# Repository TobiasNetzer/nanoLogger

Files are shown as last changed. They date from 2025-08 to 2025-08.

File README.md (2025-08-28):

# Block Diagram

Here is a simplified block diagram of the data logger. To measure the current of a device, the data logger is simply connected in series between the voltage source and the DUT/load.

The current flow creates a small voltage drop across the selected shunt resistor, which is amplified by a factor of 100. The output voltage is then measured by the microcontroller's internal ADC.
A change of the current range is also observed by the microcontroller, to correctly convert the measured current.

An external trigger signal can optionally be connected. This allows to start the measurement on a rising or falling edge. Perfect to always have the same starting point of a measurement, for example when the DUT enters active mode.

Status LEDs provide the user with information about the device's current state/mode, for example: logger in standby mode, or data recording in progress.

The captured data is buffered internally in the microcontroller and then transferred to a PC via an isolated USB 2.0 interface.

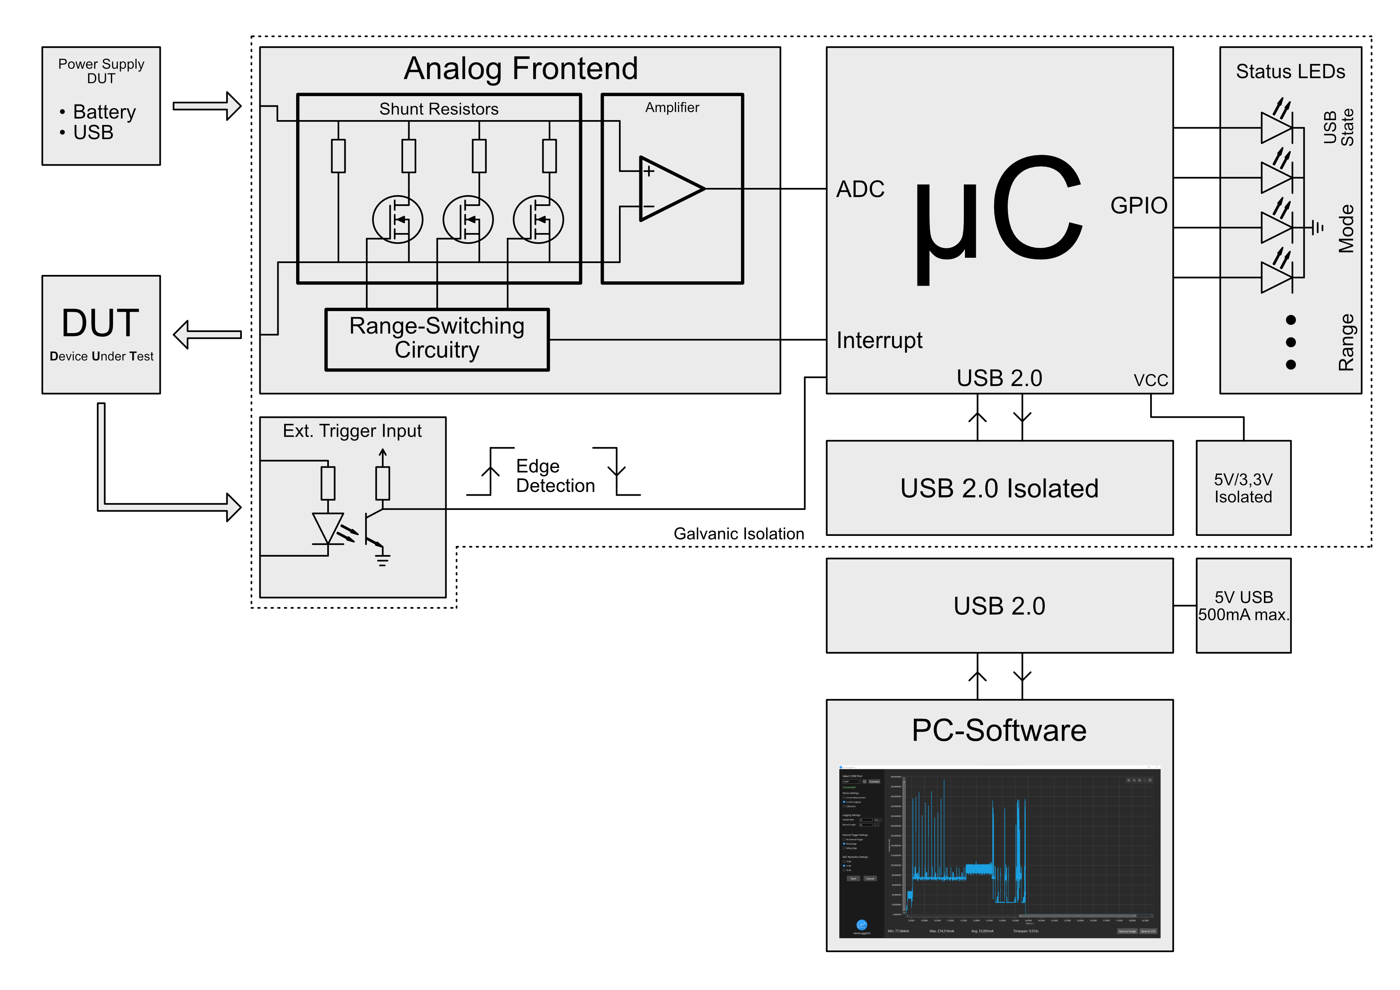
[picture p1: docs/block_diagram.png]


# Hardware

I've written a very detailed explanation as part of the project documentation. You can read more about it [here](docs/Technikerarbeit_Tobias_Netzer.pdf) if you are interested in the design aspects and my thoughts behind them. This is also where you can find all the schematics and technical drawings. The documentation was however written in German.

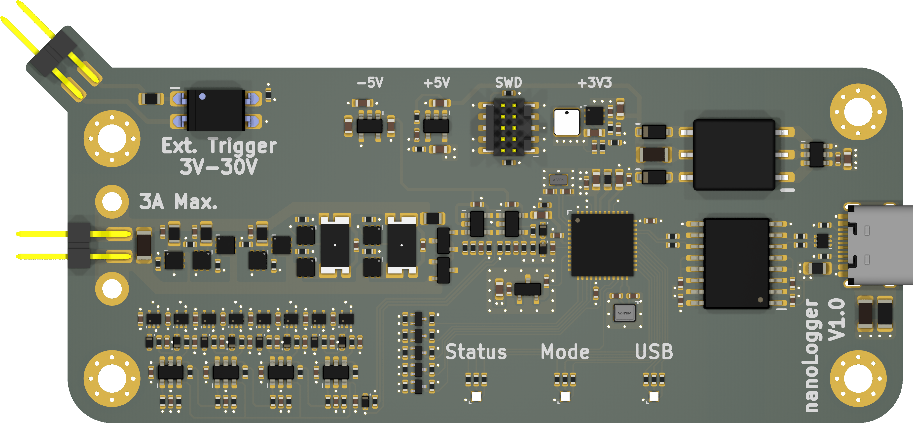
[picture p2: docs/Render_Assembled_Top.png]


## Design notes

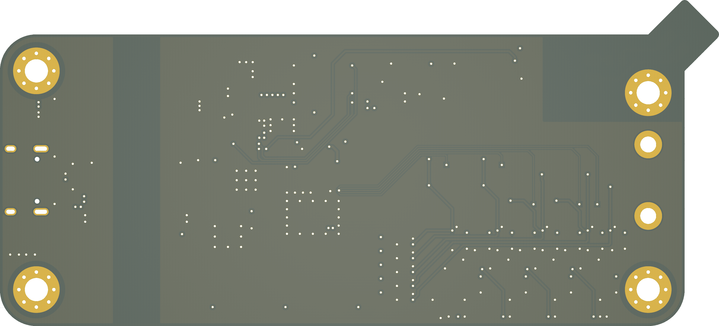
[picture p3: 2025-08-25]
docs/Render Bot.png

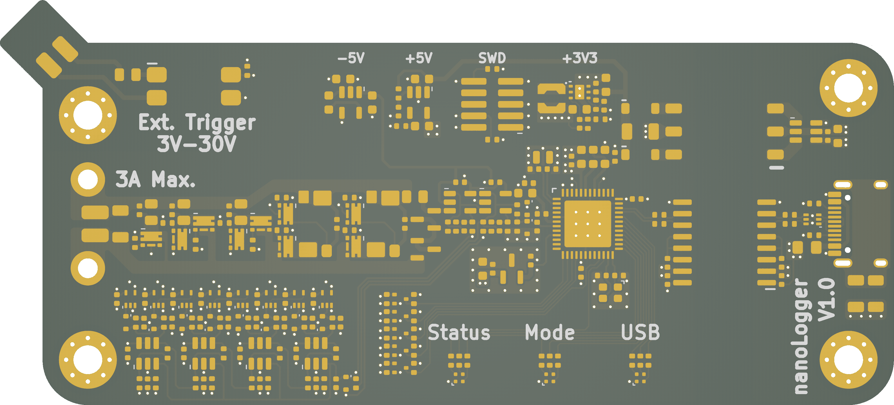
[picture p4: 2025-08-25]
docs/Render Top.png

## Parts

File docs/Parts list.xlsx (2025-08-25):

Position | Menge | Bauteilbezeichnung | Wert/Typ | Beschreibung | Hersteller | Hersteller-Nr. | Lieferant | Lieferant-Nr. | Stückpreis | Gesamtpreis
1 | 2 | C1, C35 | 10nF | 10nF-1%-1206-C0G-630V | Kemet | C1206C103FBGACAUTO | Mouser | 80-C1206C103FBGAUTO | 1.03 € | 2.06 €
2 | 6 | C2, C8, C12, C19, C23, C27 | 10µF | 10µF-20%-0603-X5R-10V | Kemet | C0603C106M8PACTU | Mouser | 80-C0603C106M8PACTU | 0.43 € | 2.58 €
3 | 33 | C3, C4, C5, C6, C7, C9, C10, C14, C20, C21, C22, C24, C26, C28, C36, C37, C38, C39, C40, C41, C42, C46, C47, C48, C49, C62, C63, C64, C65, C66, C67, C68, C69 | 100nF | 100nF-20%-0402-X7R-25V | Kemet | C0402C104M3RACTU | Mouser | 80-C0402C104M3R | 0.26 € | 8.58 €
4 | 7 | C11, C43, C44, C50, C51, C52, C53 | 22pF | 22pF-5%-0402-C0G-50V | Kemet | C0402C220J5GACTU | Mouser | 80-C0402C220J5G | 0.09 € | 0.63 €
5 | 2 | C13, C15 | 2.2µF | 2.2µF-10%-0603-X5R-10V | Kemet | C0603C225K8PACTU | Mouser | 80-C0603C225K8P | 0.22 € | 0.44 €
6 | 3 | C16, C17, C18 | 1µF | 1µF-10%-0603-X7R-25V | Kemet | C0603C105K3RACTU | Mouser | 80-C0603C105K3R | 0.26 € | 0.78 €
7 | 1 | C25 | 4.7µF | 4.7µF-20%-0603-X5R-10V | Kemet | C0603C475M8PACTU | Mouser | 80-C0603C475M8P | 0.23 € | 0.23 €
8 | 1 | C29 | 10nF | 10nF-10%-0402-X7R-50V | Kemet | C0402C103K5REC7411 | Mouser | 80-C0402C103K5RECLR | 0.10 € | 0.10 €
9 | 2 | C30, C31 | 8pF | 8pF-0.25pF-0402-C0G-50V | Kemet | CBR04C809C5GAC | Mouser | 80-CBR04C809C5G | 0.12 € | 0.24 €
10 | 2 | C32, C33 | 12pF | 12pF-10%-0402-C0G-25V | Kemet | C0402C120K3GACTU | Mouser | 80-C0402C120K3GACTU | 0.33 € | 0.66 €
11 | 1 | C34 | 100pF | 100pF-5%-0402-C0G-50V | Kemet | C0402C101J5GACTU | Mouser | 80-C0402C101J5G | 0.09 € | 0.09 €
12 | 9 | C45, C54, C55, C56, C57, C58, C59, C60, C61 | 1nF | 1nF-10%-0402-C0G-25V | Kemet | C0402C102K3GACTU | Mouser | 80-C0402C102K3G | 0.27 € | 2.43 €
13 | 1 | C70 | 10µF | 10µF-10%-1206-X7R-25V | Kemet | C1206X106K3RACTU | Mouser | 80-C1206X106K3R | 0.94 € | 0.94 €
14 | 2 | D1, D2 | MBR0520L | Schottky Dioden & Gleichrichter 0.5A 20V | onsemi | MBR0520LT3G | Mouser | 863-MBR0520LT3G | 0.36 € | 0.72 €
15 | 3 | D3, D4, D5 | Wuerth_150044M155260 | Standard-LEDs - SMD WL-SFCC SMT LED Full-color Chip | Wuerth Elektronik | 150044M155260 | Mouser | 710-150044M155260 | 0.47 € | 1.41 €
16 | 11 | D6, D7, D8, D9, D10, D11, D12, D13, D14, D15, D16 | 1PS79SB30 | Schottky Diode | Nexperia | 1PS79SB30YL | Mouser | 771-1PS79SB30YL | 0.27 € | 2.97 €
17 | 1 | J1 | USB_Type_C_Receptacle | Receptacle USB - Type C 16 8.94*7.3mm USB Connectors ROHS | Korean Hroparts Elec | USB_C_Receptacle_HRO_TYPE-C-31-M-12 | LCSC | C165948 | 0.29 € | 0.29 €
18 | 1 | J2 | SWD Header | Sockel & Kabelgehäuse High Reliability Header Strips, 0.050 pitch | Samtec | FTSH-105-01-F-DV-K | Mouser | 200-FTSH10501FDVK | 3.64 € | 3.64 €
19 | 2 | J3, J4 | 2,54mm Steckerleiste | Sockel & Kabelgehäuse .100 Surface Mount Terminal Strip | Samtec | TSM-102-01-F-SH | Mouser | 200-TSM10201FSH | 0.50 € | 1.00 €
20 | 1 | L1 | 300R 3A | Ferritperlen WE-CBF 0805 200MHz 300Ohm 3000mA AECQ2 | Wuerth Elektronik | 742792031 | Mouser | 710-742792031 | 0.20 € | 0.20 €
21 | 1 | L2 | 2.2µH | 2.2uH Shld 20% 110mOhms AECQ2 | Coilcraft | LPS3015-222MRB | Mouser | 994-LPS3015-222MRB | 1.13 € | 1.13 €
22 | 1 | L3 | 600R | Ferritperlen 600ohm 25% 440mA | TDK | MMZ1005S601HTD25 | Mouser | 810-MMZ1005S601HTD25 | 0.09 € | 0.09 €
23 | 1 | L4 | 10µH | Festinduktivitäten 0603 10uH 20% | TDK | MLZ1608E100MT | Mouser | 810-MLZ1608E100MT | 0.14 € | 0.14 €
24 | 9 | Q1, Q2, Q3, Q4, Q5, Q6, Q7, Q8, Q9 | DMN6040SFDE | N-Channel MOSFET | Diodes Incorporated | DMN6040SFDE-7 | Mouser | 621-DMN6040SFDE-7 | 0.59 € | 5.31 €
25 | 2 | Q10, Q11 | MMBTH10L | Bipolartransistor NPN | onsemi | MMBTH10LT3G | Mouser | 863-MMBTH10LT3G | 0.26 € | 0.52 €
26 | 5 | Q12, Q13, Q14, Q15, Q16 | 2N7002T | N-Channel MOSFET | Diodes Incorporated | 2N7002T-7-F | Mouser | 621-2N7002T-F | 0.38 € | 1.90 €
27 | 1 | R1 | 1M | 1M-1%-1206-250mW-50ppm | Yageo | RE1206FRE071ML | Mouser | 603-RE1206FRE071ML | 0.12 € | 0.12 €
28 | 2 | R2, R3 | 5k1 | 5.1k-1%-0402-62.5mW-50ppm | Yageo | RT0402FRE075K1L | Mouser | 603-RT0402FRE075K1L | 0.09 € | 0.18 €
29 | 4 | R4, R5, R6, R7 | 24R | 24R-1%-0402-62.5mW-50ppm | Yageo | RT0402FRE0724RL | Mouser | 603-RT0402FRE0724RL | 0.22 € | 0.88 €
30 | 10 | R8, R11, R14, R48, R50, R52, R54, R56, R60, R66 | 10k | 10k-1%-0402-62.5mW-50ppm | Yageo | RT0402FRE0710KL | Mouser | 603-RT0402FRE0710KL | 0.22 € | 2.20 €
31 | 1 | R9 | 820k | 820k-1%-0402-62.5mW-100ppm | Yageo | RC0402FR-07820KL | Mouser | 603-RC0402FR-07820KL | 0.09 € | 0.09 €
32 | 1 | R10 | 182k | 182k-1%-0402-62.5mW-50ppm | Yageo | RT0402FRE07182KL | Mouser | 603-RT0402FRE07182KL | 0.09 € | 0.09 €
33 | 1 | R12 | 1R | 1R-1%-0402-62.5mW-50ppm | Bourns | CRT0402-FZ-1R00GLF | Mouser | 652-CRT0402FZ1R00GLF | 0.09 € | 0.09 €
34 | 5 | R13, R15, R18, R21, R59 | 1k | 1k-1%-0402-62.5mW-50ppm | Yageo | RT0402FRE071KL | Mouser | 603-RT0402FRE071KL | 0.09 € | 0.45 €
35 | 3 | R16, R19, R22 | 2k8 | 2k8-1%-0402-62.5mW-50ppm | Yageo | RT0402FRE072K8L | Mouser | 603-RT0402FRE072K8L | 0.22 € | 0.66 €
36 | 3 | R17, R20, R23 | 1k5 | 1k5-1%-0402-62.5mW-50ppm | Yageo | RT0402FRE131K5L | Mouser | 603-RT0402FRE131K5L | 0.22 € | 0.66 €
37 | 2 | R24, R25 | 10k 0.05% | 10k-0.05%-0402-62.5mW-10ppm | Susumu | RG1005N-103-W-T1 | Mouser | 754-RG1005N-103-WT1 | 1.05 € | 2.10 €
38 | 1 | R26 | 10k 0,05% | 10k-0.05%-0805-1/8W-10ppm | Susumu | RG2012N-103-W-T1 | Mouser | 754-RG2012N-103-W-T1 | 0.83 € | 0.83 €
39 | 1 | R27 | 100R 0,05% | 100R-0.05%-0805-1/8W-10ppm | Susumu | RG2012N-101-W-T1 | Mouser | 754-RG2012N-101-W-T1 | 0.81 € | 0.81 €
40 | 1 | R28 | 10R 0,05% | 10R-0.05%-0805-1/8W-10ppm | Stackpole | RNCF0805AKT10R0 | Digikey | RNCF0805AKT10R0CT-ND | 0.89 € | 0.89 €
41 | 1 | R29 | 100m 0,1% | 100m-0.1%-2512-1W-15ppm | Vishay Precision Group | Y14870R10000B9R | Mouser | 71-CSM25120R1000BST | 8.09 € | 8.09 €
42 | 1 | R30 | 10m 0,1% | 10m-0.1%-2512-1W-15ppm | Vishay Precision Group | Y14870R01000B9R | Mouser | 71-CSM25120R0100BST | 7.39 € | 7.39 €
43 | 1 | R31 | 220R | 220R-1%-0805-250mW-100ppm | Yageo | RC0805JR-13220RL | Mouser | 603-RC0805JR-13220RL | 0.09 € | 0.09 €
44 | 2 | R32, R35 | 2k2 0,05% | 2.2k-0.05%-0402-100mW-10ppm | Panasonic Electronic Components | ERA-2VRW2201X | Digikey | 10-ERA-2VRW2201XCT-ND | 0.75 € | 1.50 €
45 | 2 | R33, R36 | 6k8 0,05% | 6.8k-0.05%-0402-100mW-10ppm | Panasonic Electronic Components | ERA-2VRW6801X | Digikey | 10-ERA-2VRW6801XCT-ND | 0.75 € | 1.50 €
46 | 2 | R34, R37 | 1k 0,05% | 1k-0.05%-0402-62.5mW-5ppm | Susumu | RG1005V-102-W-T1 | Mouser | 754-RG1005V-102-WT1 | 3.12 € | 6.24 €
47 | 14 | R38, R39, R40, R41, R42, R43, R44, R45, R46, R47, R49, R51, R53, R55 | 68R | 68R-1%-0402-62.5mW-100ppm | Yageo | RC0402FR-0768RL | Mouser | 603-RC0402FR-0768RL | 0.09 € | 1.26 €
48 | 1 | R57 | 10k | 10k-1%-0805-330mW-200ppm | Yageo | SR0805FR-7T10KL | Mouser | 603-SR0805FR-7T10KL | 0.70 € | 0.70 €
49 | 1 | R58 | 100k | 100k-1%-0402-62.5mW-50ppm | Yageo | RT0402FRE07100KL | Mouser | 603-RT0402FRE07100KL | 0.09 € | 0.09 €
50 | 2 | R61, R67 | 15k | 15k-1%-0402-62.5mW-100ppm | Vishay/Dale | CRCW040215K0FKEDC | Mouser | 71-CRCW040215K0FKEDC | 0.09 € | 0.18 €
51 | 2 | R62, R68 | 7M5 | 7.5M-1%-0402-62.5mW-100ppm | Vishay/Dale | CRCW04027M50FKED | Mouser | 71-CRCW04027M50FKED | 0.09 € | 0.18 €
52 | 2 | R63, R69 | 24k | 24k-1%-0402-62.5mW-100ppm | Bourns | CR0402-FX-2402GLF | Mouser | 652-CR0402FX-2402GLF | 0.09 € | 0.18 €
53 | 2 | R64, R70 | 36k | 36k-1%-0402-62.5mW-100ppm | Bourns | CR0402-FX-3602GLF | Mouser | 652-CR0402FX-3602GLF | 0.09 € | 0.18 €
54 | 2 | R65, R71 | 750k | 750k-1%-0402-62.5mW-100ppm | Bourns | CR0402-FX-7503GLF | Mouser | 652-CR0402FX-7503GLF | 0.09 € | 0.18 €
55 | 8 | R72, R73, R74, R75, R76, R77, R78, R79 | 100R | 100R-1%-0402-62.5mW-50ppm | Yageo | RT0402FRE07100RL | Mouser | 603-RT0402FRE07100RL | 0.09 € | 0.72 €
56 | 1 | TR1 | Wuerth_750315371 | Netztransformatoren MID-SN6505 TI Driver 5V 1A 320 to 480kHz | Wuerth Elektronik | 750315371 | Mouser | 710-750315371 | 2.36 € | 2.36 €
57 | 1 | U1 | USBLC6-2P6 | ESD-Entstörer/TVS-Dioden High Speed Interface Protection Low Cap | STMicroelectronics | USBLC6-2P6 | Mouser | 511-USBLC6-2P6 | 0.56 € | 0.56 €
58 | 1 | U2 | ADUM4160 | Digitale Isolatoren 8mm Creep. Full/Low Speed USB Isolator | Analog Devices | ADUM4160BRWZ | Mouser | 584-ADUM4160BRWZ | 11.22 € | 11.22 €
59 | 1 | U3 | SN6505B | Transformer driver with soft start for isolated power supplies | Texas Instruments | SN6505BQDBVTQ1 | Mouser | 595-SN6505BQDBVTQ1 | 3.03 € | 3.03 €
60 | 1 | U4 | TPS62290 | Schaltspannungsregler 2.25MHz 1A Step- Down Converter | Texas Instruments | TPS62290DRVR | Mouser | 595-TPS62290DRVR | 1.70 € | 1.70 €
61 | 1 | U5 | LP2981IM5X-5.0 | LDO Spannungs-Regulator 100-mA, 16-V, low-dropout voltage regulator with enable 5-SOT-23 -40 to 125 | Texas Instruments | LP2981IM5X-5.0/NOPB | Mouser | 926-LP2981IM5X50NOPB | 1.13 € | 1.13 €
62 | 1 | U6 | TPS60400 | Schaltspannungsregler | Texas Instruments | TPS60401QDBVRQ1 | Mouser | 595-TPS60401QDBVRQ1 | 1.22 € | 1.22 €
63 | 1 | U7 | ATSAMD51G18A-M | ARM Mikrocontroller - MCU 120MHZ 256KB Flash 48 QFN | Microchip Technology / Atmel | ATSAMD51G18A-MF | Mouser | 556-ATSAMD51G18A-MF | 4.81 € | 4.81 €
64 | 1 | U8 | ISL21080CIH315Z-TK | Spannungsreferenzen PBFREE PRECISION 1 5V LW V FGA"F 0 5% | Renesas/Intersil | ISL21080CIH315Z-TK | Mouser | 968-ISL21080CIH315ZT | 1.87 € | 1.87 €
65 | 2 | U9, U10 | OPA189 | Präzisionsverstärker | Texas Instruments | OPA189IDBVT | Mouser | 595-OPA189IDBVT | 2.86 € | 5.72 €
66 | 1 | U11 | PS2533L-1-F3-A | Transistor-Ausgangsoptokoppler Optocoupler 4-pin DIP | Renesas Electronics | PS2533L-1-F3-A | Mouser | 968-PS2533L-1-F3-A | 1.66 € | 1.66 €
67 | 4 | U12, U13, U14, U15 | LMV761 | Präzisionskomparator | Texas Instruments | LMV761MFX | Mouser | 926-LMV761MFX | 2.24 € | 8.96 €
68 | 4 | U16, U17, U18, U23 | SN74AHC1G04 | Logik Gatter NOT | Texas Instruments | SN74AHC1G04DRLR | Mouser | 595-SN74AHC1G04DRLR | 0.39 € | 1.56 €
69 | 1 | U19 | SN74AHC1G32 | Logik Gatter OR | Texas Instruments | SN74AHC1G32DRLRG4 | Mouser | 595-74AHC1G32DRLRG4 | 0.44 € | 0.44 €
70 | 3 | U20, U21, U22 | SN74AHC1G02 | Logik Gatter NOR | Texas Instruments | SN74AHC1G02DRLR | Mouser | 595-SN74AHC1G02DRLR | 0.43 € | 1.29 €
71 | 1 | Y1 | ABM10W-48MHZ | Quarze CRYSTAL 48.0000MHZ 8PF SMD | Abracon | ABM10W-48.0000MHZ-8-K1Z-T3 | Mouser | 815-10W48-8K1ZT | 0.58 € | 0.58 €
72 | 1 | Y2 | ABS06-32.768K | Quarze 32.768K HZ 12.5PF -40+85C | Abracon | ABS06-32.768KHZ-T | Mouser | 815-ABS06-32.768K-T | 1.29 € | 1.29 €
 |  |  |  |  |  |  |  |  |  | 127.01 €

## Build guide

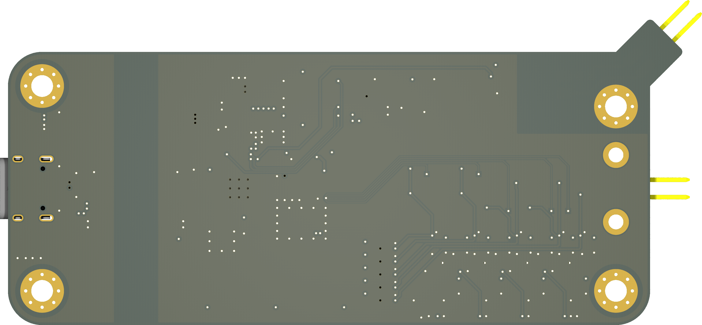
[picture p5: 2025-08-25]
docs/Render_Assembled_Bot.png

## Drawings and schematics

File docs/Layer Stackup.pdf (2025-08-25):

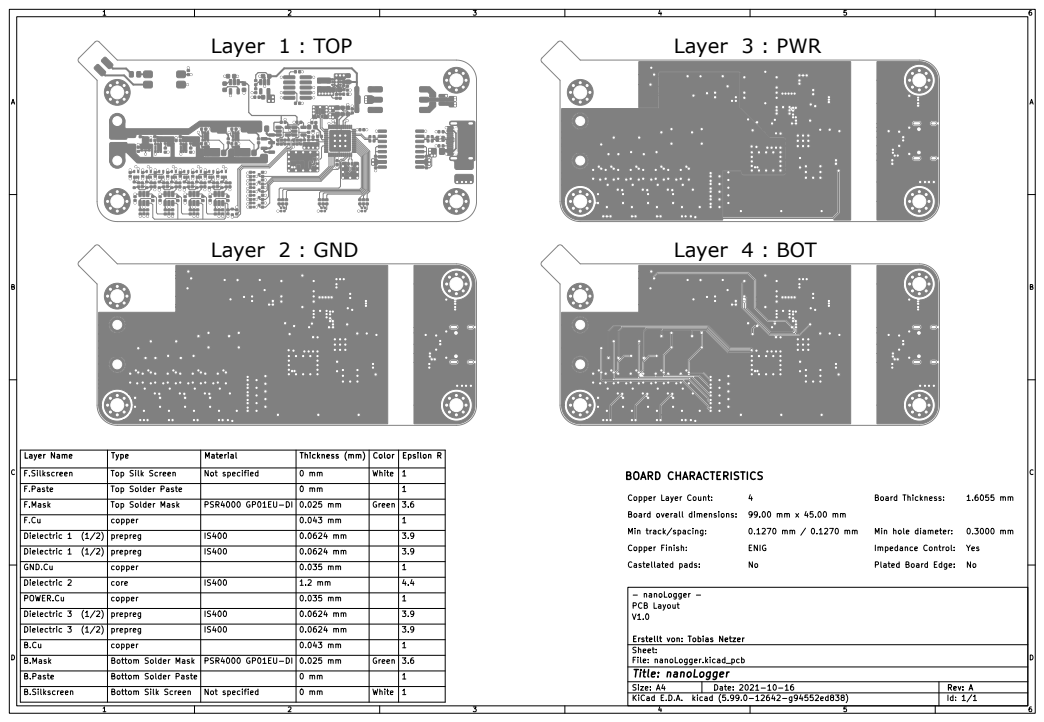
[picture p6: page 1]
Layer 1 : TOP; Layer 3 : PWR; Layer 2 : GND; Layer 4 : BOT

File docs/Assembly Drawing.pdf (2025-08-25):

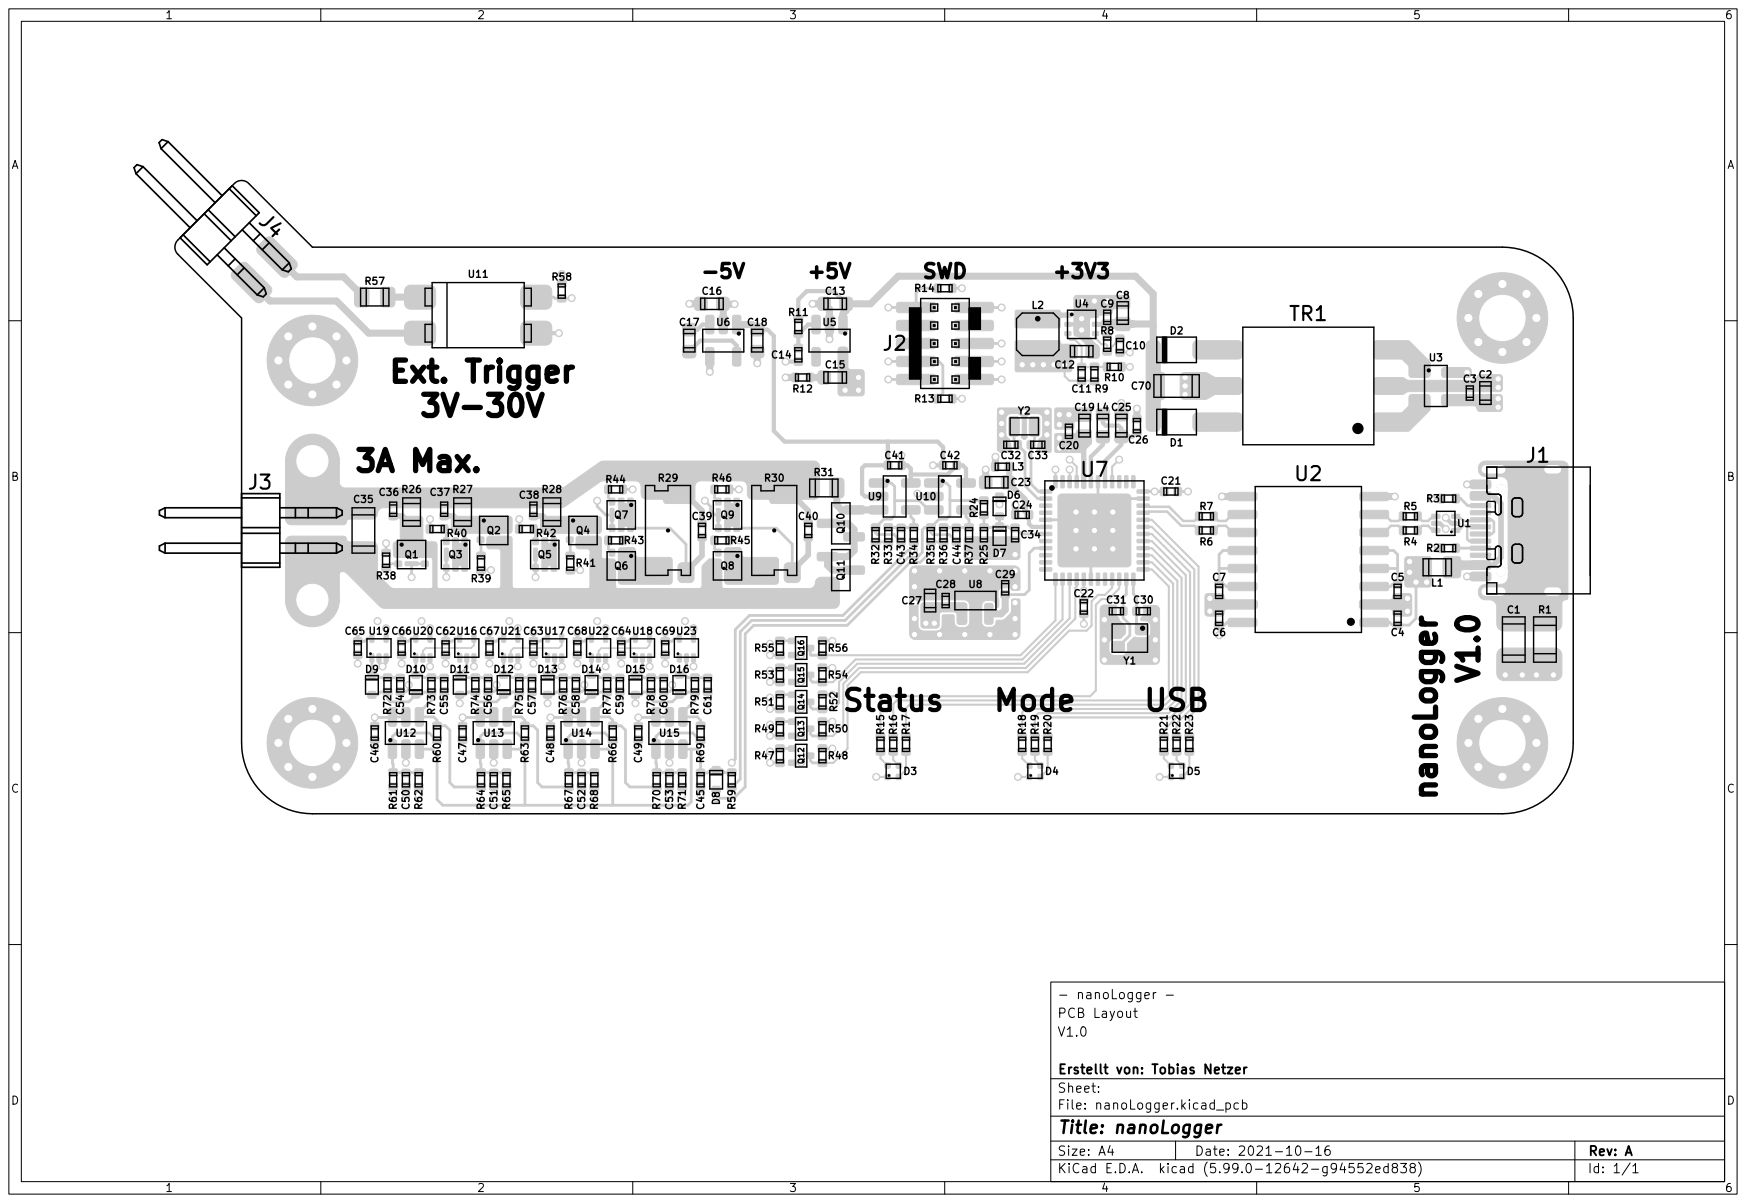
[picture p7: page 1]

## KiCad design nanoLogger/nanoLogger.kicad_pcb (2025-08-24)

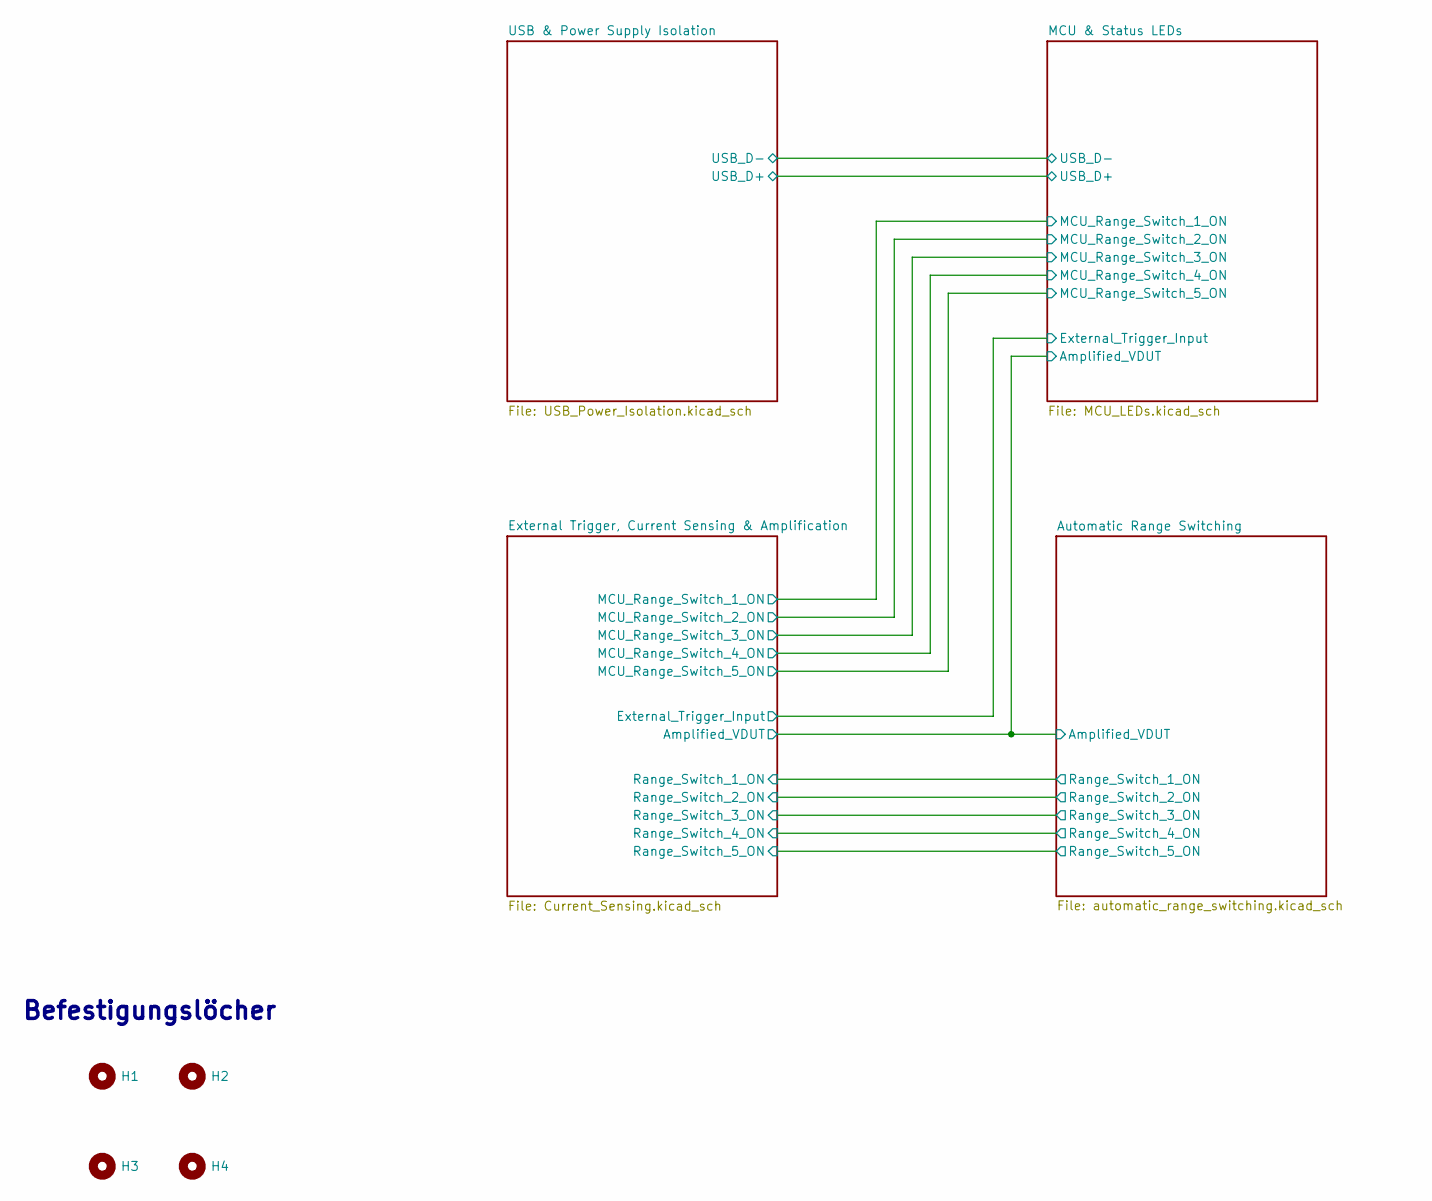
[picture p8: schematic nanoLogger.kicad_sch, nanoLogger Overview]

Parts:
H1, H2, H3, H4: MountingHole_M3

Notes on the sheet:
Befestigungslöcher

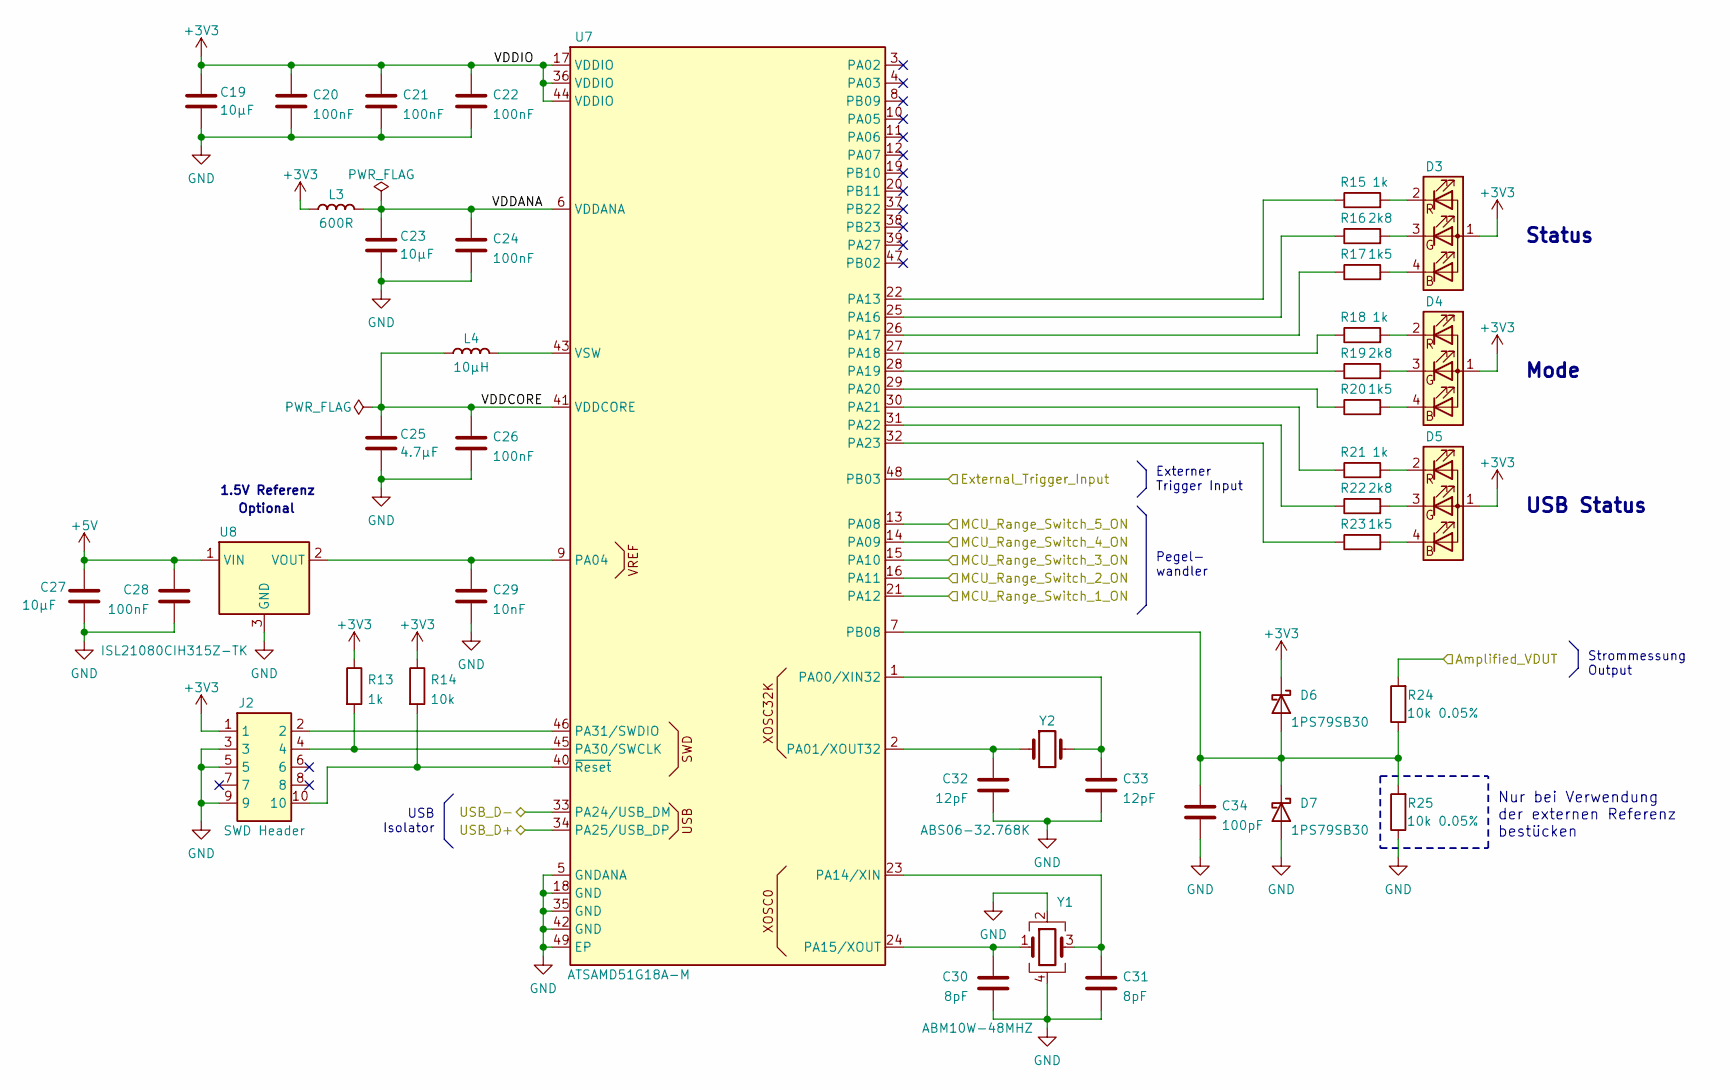
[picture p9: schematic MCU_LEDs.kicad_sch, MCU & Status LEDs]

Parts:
C19, C23, C27: 10µF; Capacitor_0603
C20, C21, C22, C24, C26, C28: 100nF; Capacitor_0402
C25: 4.7µF; Capacitor_0603
C29: 10nF; Capacitor_0402
C30, C31: 8pF; Capacitor_0402
C32, C33: 12pF; Capacitor_0402
C34: 100pF; Capacitor_0402
D3, D4, D5: Wuerth_150044M155260; LED_0404
D6, D7: 1PS79SB30; SOD523
J2: SWD Header; SAMTEC_FTSH-105-XX-X-DV
L3: 600R; Inductor_0402
L4: 10µH; Inductor_0603
R13, R15, R18, R21: 1k; Resistor_0402
R14: 10k; Resistor_0402
R16, R19, R22: 2k8; Resistor_0402
R17, R20, R23: 1k5; Resistor_0402
R24, R25: 10k 0.05%; Resistor_0402
U7: ATSAMD51G18A-M; VQFN-48
U8: ISL21080CIH315Z-TK; SOT-23
Y1: ABM10W-48MHZ; Abracon_ABM10_2.5x2.0mm
Y2: ABS06-32.768K; Abracon_ABS06

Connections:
+3V3: C19.2, C20.1, C21.1, C22.1, D3.1 (A), D4.1 (A), D5.1 (A), D6.1 (K), J2.1, L3.1, R13.1, R14.1, U7.17 (VDDIO), U7.36 (VDDIO), U7.44 (VDDIO); also elsewhere on the board
+5V: C27.2, C28.1, U8.1 (VIN); also elsewhere on the board
/Automatic Range Switching/Amplified_VDUT: R24.2; also elsewhere on the board
/External Trigger, Current Sensing & Amplification/External_Trigger_Input: U7.48 (PB03); also elsewhere on the board
/External Trigger, Current Sensing & Amplification/MCU_Range_Switch_1_ON: U7.21 (PA12); also elsewhere on the board
/External Trigger, Current Sensing & Amplification/MCU_Range_Switch_2_ON: U7.16 (PA11); also elsewhere on the board
/External Trigger, Current Sensing & Amplification/MCU_Range_Switch_3_ON: U7.15 (PA10); also elsewhere on the board
/External Trigger, Current Sensing & Amplification/MCU_Range_Switch_4_ON: U7.14 (PA09); also elsewhere on the board
/External Trigger, Current Sensing & Amplification/MCU_Range_Switch_5_ON: U7.13 (PA08); also elsewhere on the board
/MCU & Status LEDs/USB_D+: U7.34 (PA25/USB_DP); also elsewhere on the board
/MCU & Status LEDs/USB_D-: U7.33 (PA24/USB_DM); also elsewhere on the board
/MCU & Status LEDs/VDDANA: C23.2, C24.1, L3.2, U7.6 (VDDANA)
/MCU & Status LEDs/VDDCORE: C25.2, C26.1, L4.1, U7.41 (VDDCORE)
GND: C19.1, C20.2, C21.2, C22.2, C23.1, C24.2, C25.1, C26.2, C27.1, C28.2, C29.2, C30.2, C31.2, C32.2, C33.2, C34.2, D7.2 (A), J2.3, J2.5, J2.9, R25.1, U7.5 (GNDANA), U7.18 (GND), U7.35 (GND), U7.42 (GND), U7.49 (EP), U8.3 (GND), Y1.2, Y1.4; also elsewhere on the board
unnamed: C29.1, U7.9 (PA04), U8.2 (VOUT)
unnamed: C30.1, U7.24 (PA15/XOUT), Y1.1
unnamed: C31.1, U7.23 (PA14/XIN), Y1.3
unnamed: C32.1, U7.2 (PA01/XOUT32), Y2.1
unnamed: C33.1, U7.1 (PA00/XIN32), Y2.2
unnamed: C34.1, D6.2 (A), D7.1 (K), R24.1, R25.2, U7.7 (PB08)
unnamed: D3.2 (RK), R15.2
unnamed: D3.3 (GK), R16.2
unnamed: D3.4 (BK), R17.2
unnamed: D4.2 (RK), R18.2
unnamed: D4.3 (GK), R19.2
unnamed: D4.4 (BK), R20.2
unnamed: D5.2 (RK), R21.2
unnamed: D5.3 (GK), R22.2
unnamed: D5.4 (BK), R23.2
unnamed: J2.2, U7.46 (PA31/SWDIO)
unnamed: J2.4, R13.2, U7.45 (PA30/SWCLK)
unnamed: J2.10, R14.2, U7.40 (~Reset)
unnamed: L4.2, U7.43 (VSW)
unnamed: R15.1, U7.22 (PA13)
unnamed: R16.1, U7.25 (PA16)
unnamed: R17.1, U7.26 (PA17)
unnamed: R18.1, U7.27 (PA18)
unnamed: R19.1, U7.28 (PA19)
unnamed: R20.1, U7.29 (PA20)
unnamed: R21.1, U7.30 (PA21)
unnamed: R22.1, U7.31 (PA22)
unnamed: R23.1, U7.32 (PA23)

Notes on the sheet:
Optional
Status
Strommessung Output
Externer Trigger Input
USB Isolator
Pegel- wandler
Mode
Nur bei Verwendung der externen Referenz bestücken
USB Status
1.5V Referenz

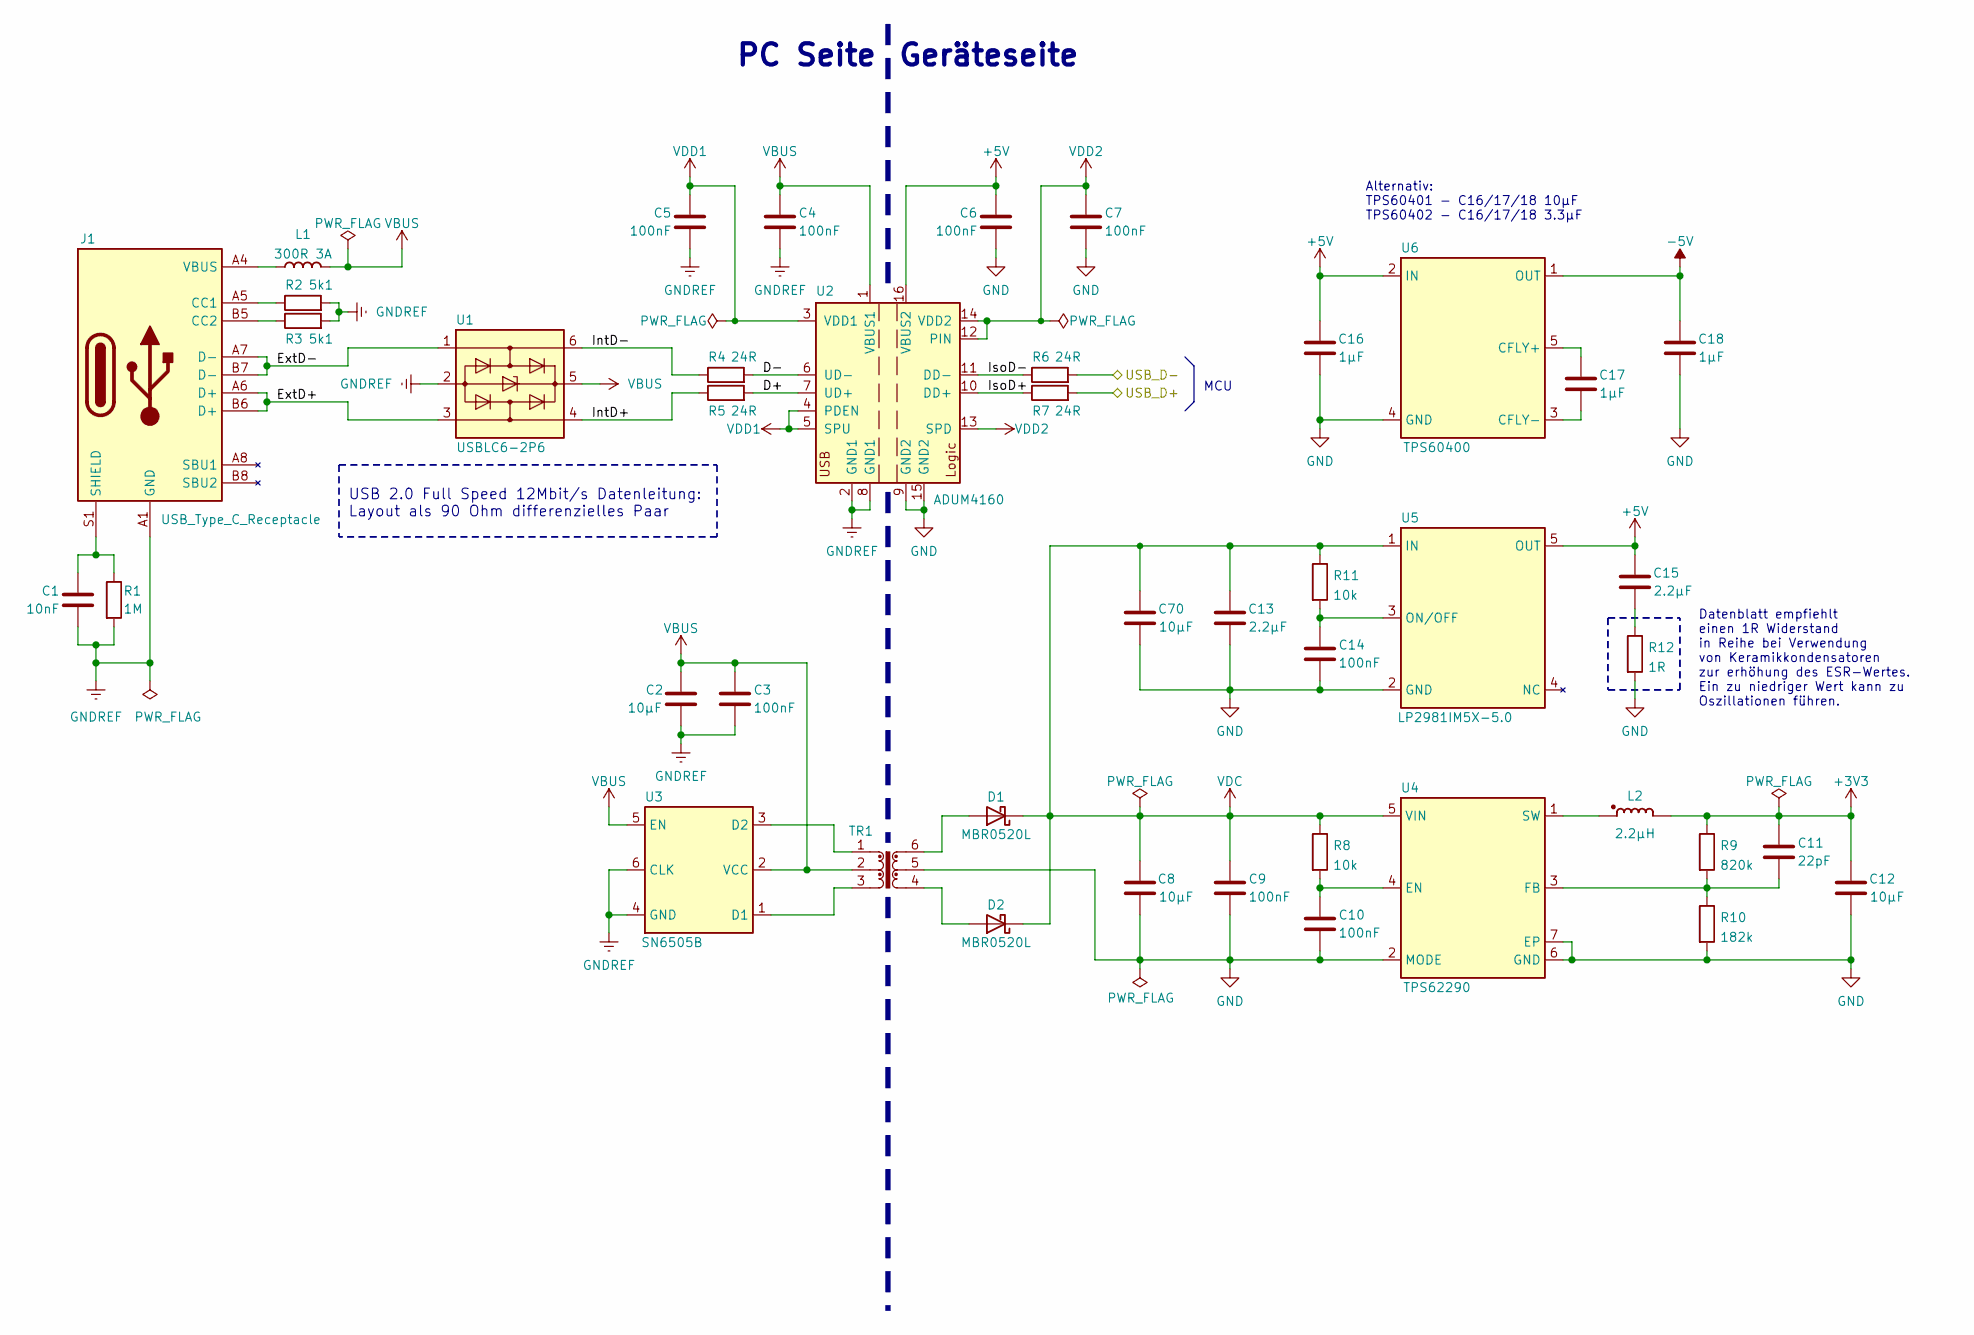
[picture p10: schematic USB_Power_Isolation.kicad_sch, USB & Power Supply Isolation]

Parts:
C1: 10nF; Capacitor_1206
C2, C8, C12: 10µF; Capacitor_0603
C3, C4, C5, C6, C7, C9, C10, C14: 100nF; Capacitor_0402
C11: 22pF; Capacitor_0402
C13, C15: 2.2µF; Capacitor_0603
C16, C17, C18: 1µF; Capacitor_0603
C70: 10µF; Capacitor_1206
D1, D2: MBR0520L; SOD-123
J1: USB_Type_C_Receptacle; USB_C_Receptacle_HRO_TYPE-C-31-M-12
L1: 300R 3A; Inductor_0805
L2: 2.2µH; LPS3015
R1: 1M; Resistor_1206
R2, R3: 5k1; Resistor_0402
R4, R5, R6, R7: 24R; Resistor_0402
R8, R11: 10k; Resistor_0402
R9: 820k; Resistor_0402
R10: 182k; Resistor_0402
R12: 1R; Resistor_0402
TR1: Wuerth_750315371; Transformer_Wuerth_750315371
U1: USBLC6-2P6; SOT-666
U2: ADUM4160; SOIC-16W
U3: SN6505B; SOT-23-6
U4: TPS62290; SON-6
U5: LP2981IM5X-5.0; SOT-23-5
U6: TPS60400; SOT-23-5

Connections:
+3V3: C11.1, C12.2, L2.2, R9.1; also elsewhere on the board
+5V: C6.1, C15.2, C16.2, U2.16 (VBUS2), U5.5 (OUT), U6.2 (IN); also elsewhere on the board
-5V: C18.2, U6.1 (OUT); also elsewhere on the board
/MCU & Status LEDs/USB_D+: R7.2; also elsewhere on the board
/MCU & Status LEDs/USB_D-: R6.2; also elsewhere on the board
/USB & Power Supply Isolation/D+: R5.2, U2.7 (UD+)
/USB & Power Supply Isolation/D-: R4.2, U2.6 (UD-)
/USB & Power Supply Isolation/ExtD+: J1.A6 (D+), J1.B6 (D+), U1.3 (I/O2)
/USB & Power Supply Isolation/ExtD-: J1.A7 (D-), J1.B7 (D-), U1.1 (I/O1)
/USB & Power Supply Isolation/IntD+: R5.1, U1.4 (I/O2)
/USB & Power Supply Isolation/IntD-: R4.1, U1.6 (I/O1)
/USB & Power Supply Isolation/IsoD+: R7.1, U2.10 (DD+)
/USB & Power Supply Isolation/IsoD-: R6.1, U2.11 (DD-)
GND: C6.2, C7.2, C8.1, C9.2, C10.2, C12.1, C13.1, C14.2, C16.1, C18.1, C70.2, R10.2, R12.2, TR1.5, U2.9 (GND2), U2.15 (GND2), U4.2 (MODE), U4.6 (GND), U4.7 (EP), U5.2 (GND), U6.4 (GND); also elsewhere on the board
GNDREF: C1.2, C2.1, C3.2, C4.2, C5.2, J1.A1 (GND), J1.A12 (GND), J1.B1 (GND), J1.B12 (GND), R1.2, R2.2, R3.2, U1.2 (GND), U2.2 (GND1), U2.8 (GND1), U3.4 (GND), U3.6 (CLK)
unnamed: C1.1, J1.S1 (SHIELD), R1.1
unnamed: C10.1, R8.2, U4.4 (EN)
unnamed: C11.2, R9.2, R10.1, U4.3 (FB)
unnamed: C14.1, R11.2, U5.3 (ON/OFF)
unnamed: C15.1, R12.1
unnamed: C17.1, U6.3 (CFLY-)
unnamed: C17.2, U6.5 (CFLY+)
unnamed: D1.2 (A), TR1.6
unnamed: D2.2 (A), TR1.4
unnamed: J1.A4 (VBUS), J1.A9 (VBUS), J1.B4 (VBUS), J1.B9 (VBUS), L1.1
unnamed: J1.A5 (CC1), R2.1
unnamed: J1.B5 (CC2), R3.1
unnamed: L2.1, U4.1 (SW)
unnamed: TR1.1, U3.3 (D2)
unnamed: TR1.3, U3.1 (D1)
VBUS: C2.2, C3.1, C4.1, L1.2, TR1.2, U1.5 (VBUS), U2.1 (VBUS1), U3.2 (VCC), U3.5 (EN)
VDC: C8.2, C9.1, C13.2, C70.1, D1.1 (K), D2.1 (K), R8.1, R11.1, U4.5 (VIN), U5.1 (IN)
VDD1: C5.1, U2.3 (VDD1), U2.4 (PDEN), U2.5 (SPU)
VDD2: C7.1, U2.12 (PIN), U2.13 (SPD), U2.14 (VDD2)

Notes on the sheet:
Geräteseite
MCU
PC Seite
Alternativ: TPS60401 - C16/17/18 10µF TPS60402 - C16/17/18 3.3µF
USB 2.0 Full Speed 12Mbit/s Datenleitung: Layout als 90 Ohm differenzielles Paar
Datenblatt empfiehlt einen 1R Widerstand in Reihe bei Verwendung von Keramikkondensatoren zur erhöhung des ESR-Wertes. Ein zu niedriger Wert kann zu Oszillationen führen.

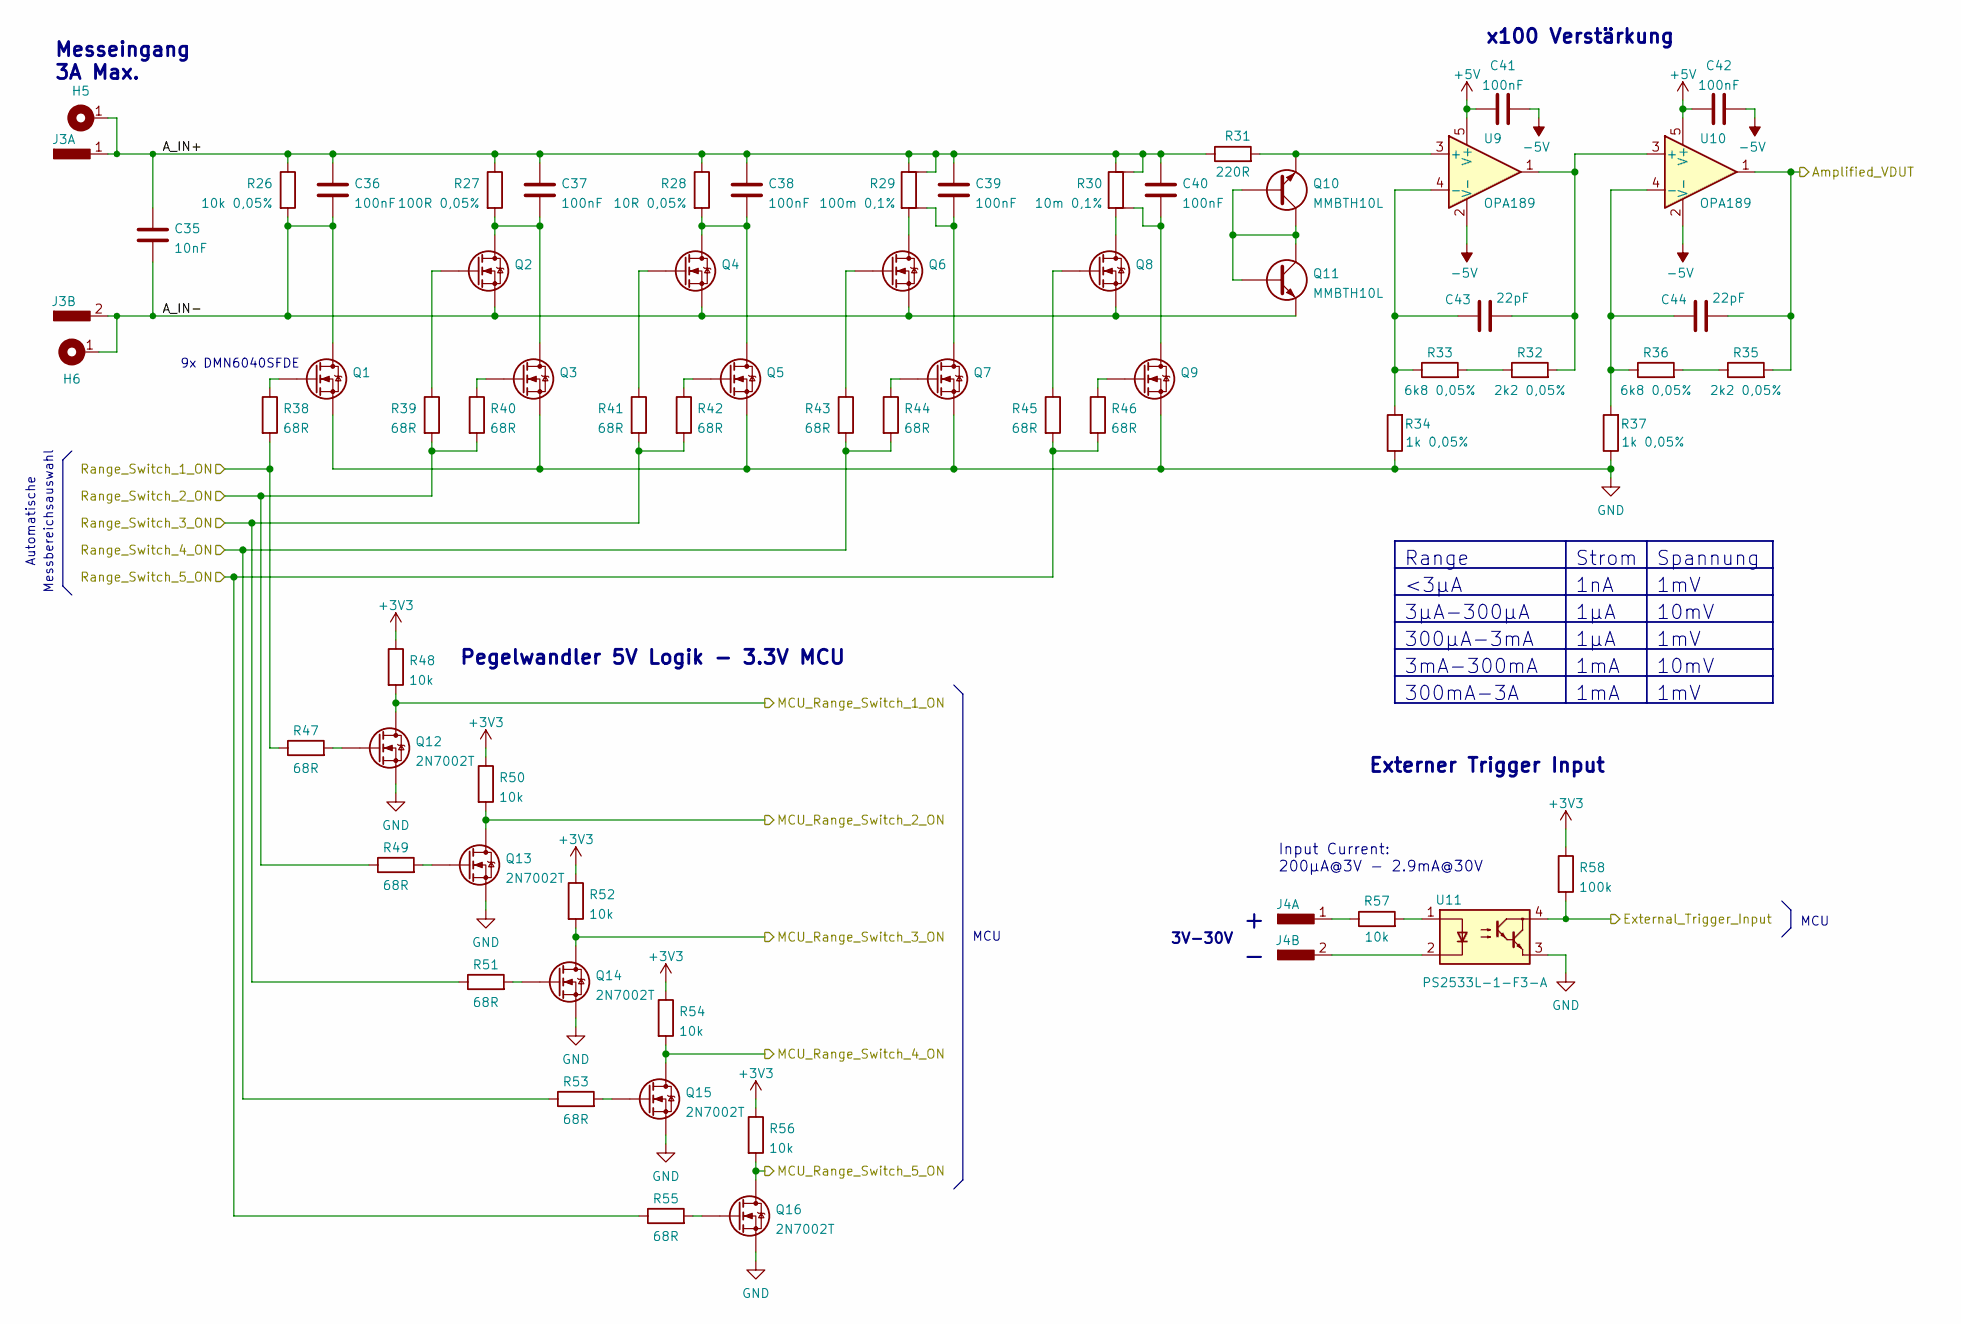
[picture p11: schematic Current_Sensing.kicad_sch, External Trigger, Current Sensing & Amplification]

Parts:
C35: 10nF; Capacitor_1206
C36, C37, C38, C39, C40, C41, C42: 100nF; Capacitor_0402
C43, C44: 22pF; Capacitor_0402
H5, H6: MountingHole_M2
J3, J4: PinHeader_2_54mm_2pol_smd; PinHeader_Male_2_54mm_2pin_smd
Q1, Q2, Q3, Q4, Q5, Q6, Q7, Q8, Q9: DMN6040SFDE; UDFN2020-6_Type-E
Q10, Q11: MMBTH10L; SOT-23
Q12, Q13, Q14, Q15, Q16: 2N7002T; SOT-523
R26: 10k 0,05%; Resistor_0805
R27: 100R 0,05%; Resistor_0805
R28: 10R 0,05%; Resistor_0805
R29: 100m 0,1%; Resistor_CSM2512
R30: 10m 0,1%; Resistor_CSM2512
R31: 220R; Resistor_0805
R32, R35: 2k2 0,05%; Resistor_0402
R33, R36: 6k8 0,05%; Resistor_0402
R34, R37: 1k 0,05%; Resistor_0402
R38, R39, R40, R41, R42, R43, R44, R45, R46, R47, R49, R51, R53, R55: 68R; Resistor_0402
R48, R50, R52, R54, R56: 10k; Resistor_0402
R57: 10k; Resistor_0805
R58: 100k; Resistor_0402
U9, U10: OPA189; SOT-23-5
U11: PS2533L-1-F3-A; DIP-4

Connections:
+3V3: R48.1, R50.1, R52.1, R54.1, R56.1, R58.1; also elsewhere on the board
+5V: C41.1, C42.1, U9.5 (V+), U10.5 (V+); also elsewhere on the board
-5V: C41.2, C42.2, U9.2 (V-), U10.2 (V-); also elsewhere on the board
/Automatic Range Switching/Amplified_VDUT: C44.2, R35.2, U10.1; also elsewhere on the board
/Automatic Range Switching/Range_Switch_1_ON: R38.2, R47.1; also elsewhere on the board
/Automatic Range Switching/Range_Switch_2_ON: R39.2, R40.2, R49.1; also elsewhere on the board
/Automatic Range Switching/Range_Switch_3_ON: R41.2, R42.2, R51.1; also elsewhere on the board
/Automatic Range Switching/Range_Switch_4_ON: R43.2, R44.2, R53.1; also elsewhere on the board
/Automatic Range Switching/Range_Switch_5_ON: R45.2, R46.2, R55.1; also elsewhere on the board
/External Trigger, Current Sensing & Amplification/A_IN+: C35.1, C36.1, C37.1, C38.1, C39.1, C40.1, H5.1, J3.1, R26.1, R27.1, R28.1, R29.1, R29.2, R30.1, R30.2, R31.1
/External Trigger, Current Sensing & Amplification/A_IN-: C35.2, C36.2, H6.1, J3.2, Q1.1 (D), Q1.2 (D), Q1.5 (D), Q1.6 (D), Q1.7 (D), Q2.4 (S), Q2.8 (S), Q4.4 (S), Q4.8 (S), Q6.4 (S), Q6.8 (S), Q8.4 (S), Q8.8 (S), Q11.2 (E), R26.2
/External Trigger, Current Sensing & Amplification/External_Trigger_Input: R58.2, U11.4; also elsewhere on the board
/External Trigger, Current Sensing & Amplification/MCU_Range_Switch_1_ON: Q12.3 (D), R48.2; also elsewhere on the board
/External Trigger, Current Sensing & Amplification/MCU_Range_Switch_2_ON: Q13.3 (D), R50.2; also elsewhere on the board
/External Trigger, Current Sensing & Amplification/MCU_Range_Switch_3_ON: Q14.3 (D), R52.2; also elsewhere on the board
/External Trigger, Current Sensing & Amplification/MCU_Range_Switch_4_ON: Q15.3 (D), R54.2; also elsewhere on the board
/External Trigger, Current Sensing & Amplification/MCU_Range_Switch_5_ON: Q16.3 (D), R56.2; also elsewhere on the board
GND: Q1.4 (S), Q1.8 (S), Q3.4 (S), Q3.8 (S), Q5.4 (S), Q5.8 (S), Q7.4 (S), Q7.8 (S), Q9.4 (S), Q9.8 (S), Q12.2 (D), Q13.2 (D), Q14.2 (D), Q15.2 (D), Q16.2 (D), R34.1, R37.1, U11.3; also elsewhere on the board
unnamed: C37.2, Q2.1 (D), Q2.2 (D), Q2.5 (D), Q2.6 (D), Q2.7 (D), Q3.1 (D), Q3.2 (D), Q3.5 (D), Q3.6 (D), Q3.7 (D), R27.2
unnamed: C38.2, Q4.1 (D), Q4.2 (D), Q4.5 (D), Q4.6 (D), Q4.7 (D), Q5.1 (D), Q5.2 (D), Q5.5 (D), Q5.6 (D), Q5.7 (D), R28.2
unnamed: C39.2, Q7.1 (D), Q7.2 (D), Q7.5 (D), Q7.6 (D), Q7.7 (D), R29.3
unnamed: C40.2, Q9.1 (D), Q9.2 (D), Q9.5 (D), Q9.6 (D), Q9.7 (D), R30.3
unnamed: C43.1, R33.1, R34.2, U9.4 (-)
unnamed: C43.2, R32.2, U9.1, U10.3 (+)
unnamed: C44.1, R36.1, R37.2, U10.4 (-)
unnamed: J4.1, R57.1
unnamed: J4.2, U11.2
unnamed: Q1.3 (G), R38.1
unnamed: Q2.3 (G), R39.1
unnamed: Q3.3 (G), R40.1
unnamed: Q4.3 (G), R41.1
unnamed: Q5.3 (G), R42.1
unnamed: Q6.1 (D), Q6.2 (D), Q6.5 (D), Q6.6 (D), Q6.7 (D), R29.4
unnamed: Q6.3 (G), R43.1
unnamed: Q7.3 (G), R44.1
unnamed: Q8.1 (D), Q8.2 (D), Q8.5 (D), Q8.6 (D), Q8.7 (D), R30.4
unnamed: Q8.3 (G), R45.1
unnamed: Q9.3 (G), R46.1
unnamed: Q10.1 (B), Q10.3 (C), Q11.1 (B), Q11.3 (C)
unnamed: Q10.2 (E), R31.2, U9.3 (+)
unnamed: Q12.1 (G), R47.2
unnamed: Q13.1 (G), R49.2
unnamed: Q14.1 (G), R51.2
unnamed: Q15.1 (G), R53.2
unnamed: Q16.1 (G), R55.2
unnamed: R32.1, R33.2
unnamed: R35.1, R36.2
unnamed: R57.2, U11.1

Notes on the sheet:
Input Current: 200µA@3V - 2.9mA@30V
10mV
1mA
Pegelwandler 5V Logik - 3.3V MCU
300µA-3mA
Externer Trigger Input
Range
1mV
Messeingang 3A Max.
MCU
Spannung
Automatische
3V-30V
300mA-3A
9x DMN6040SFDE
1µA
3mA-300mA
Messbereichsauswahl
x100 Verstärkung
3µA-300µA
Strom
1nA
<3µA

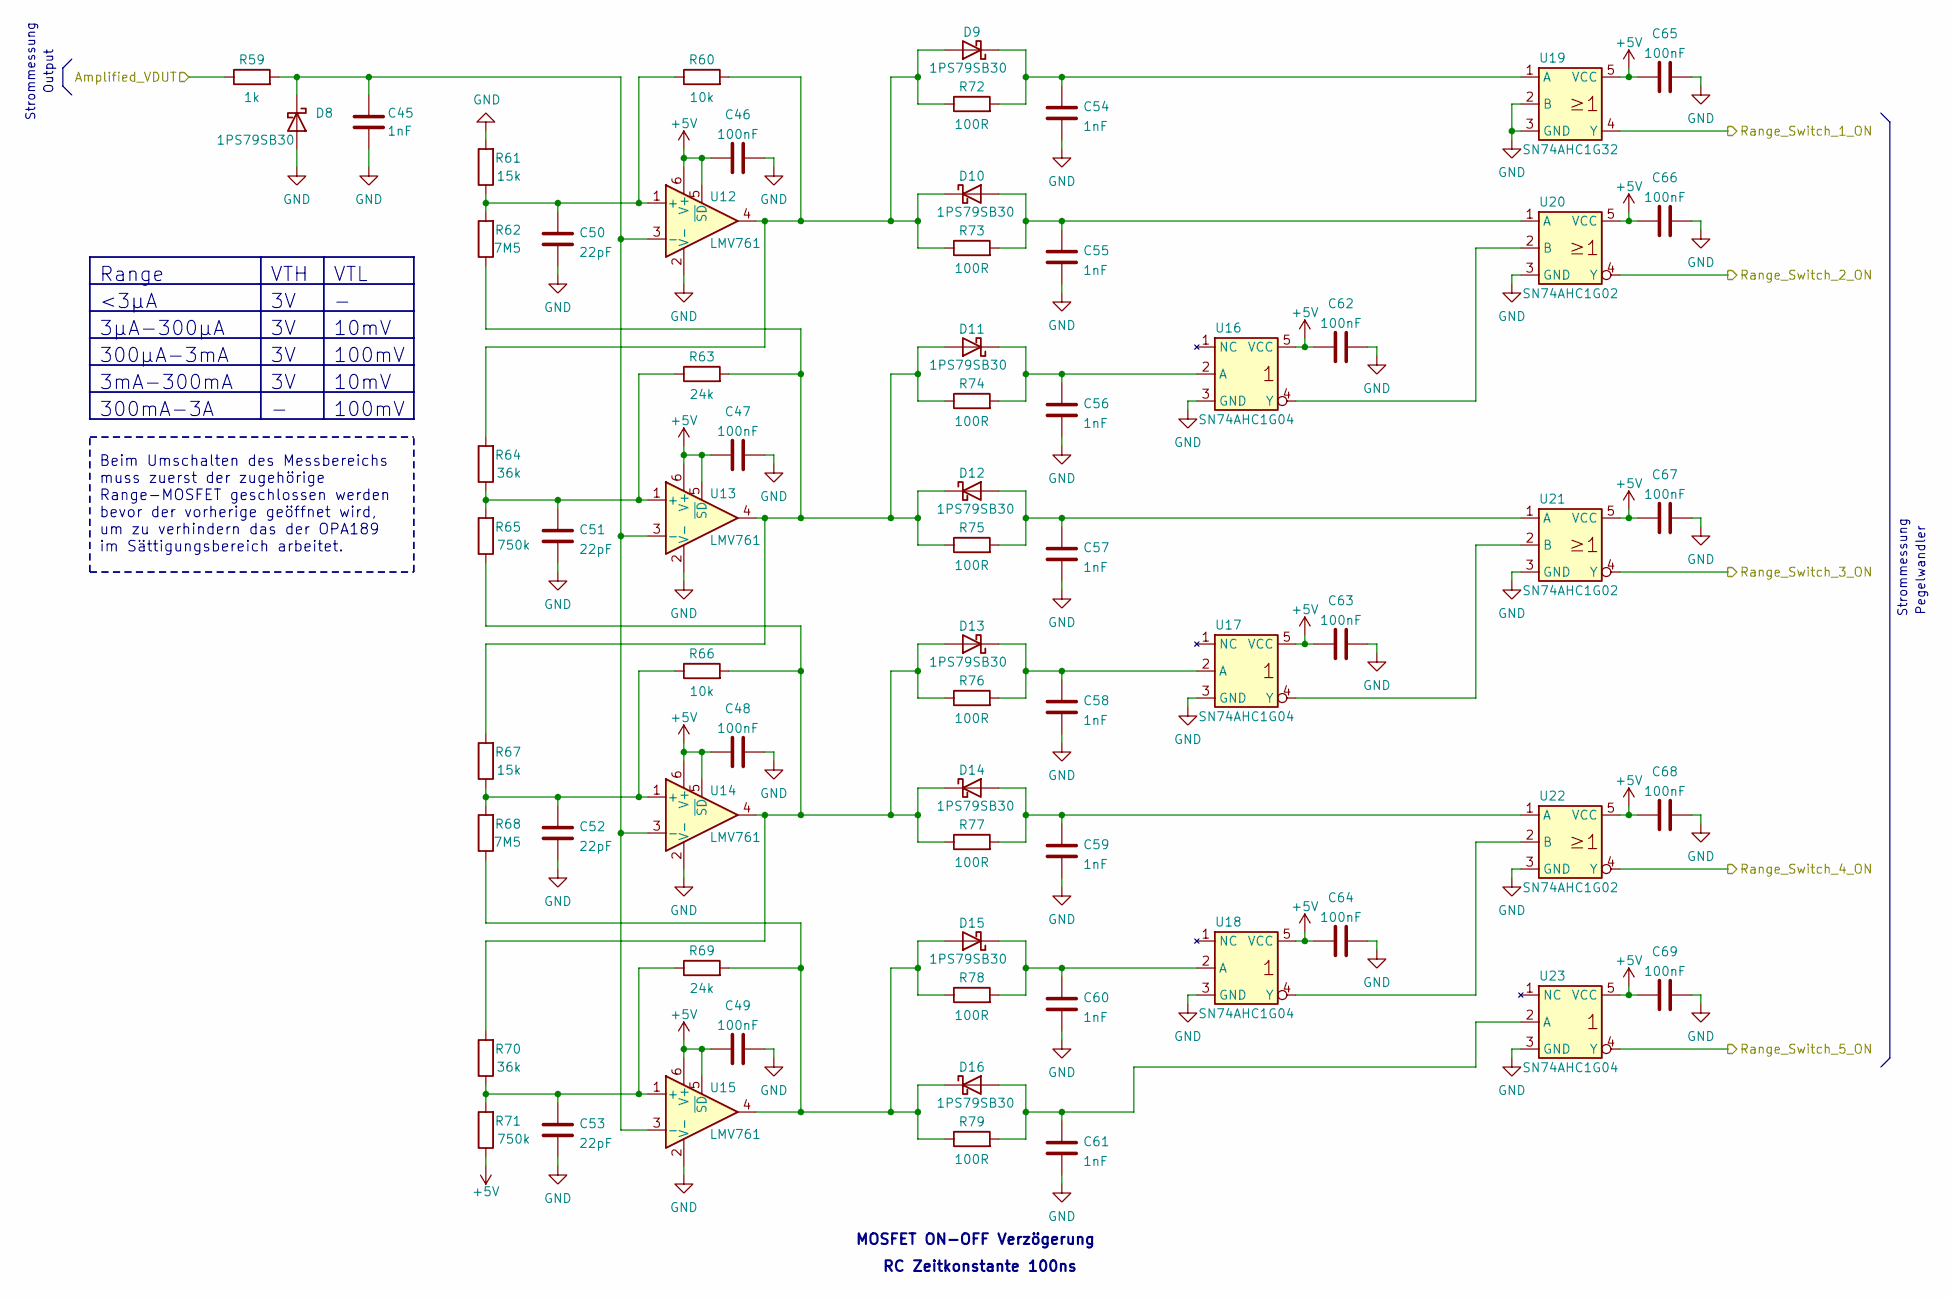
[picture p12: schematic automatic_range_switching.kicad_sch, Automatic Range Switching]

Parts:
C45, C54, C55, C56, C57, C58, C59, C60, C61: 1nF; Capacitor_0402
C46, C47, C48, C49, C62, C63, C64, C65, C66, C67, C68, C69: 100nF; Capacitor_0402
C50, C51, C52, C53: 22pF; Capacitor_0402
D8, D9, D10, D11, D12, D13, D14, D15, D16: 1PS79SB30; SOD523
R59: 1k; Resistor_0402
R60, R66: 10k; Resistor_0402
R61, R67: 15k; Resistor_0402
R62, R68: 7M5; Resistor_0402
R63, R69: 24k; Resistor_0402
R64, R70: 36k; Resistor_0402
R65, R71: 750k; Resistor_0402
R72, R73, R74, R75, R76, R77, R78, R79: 100R; Resistor_0402
U12, U13, U14, U15: LMV761; SOT-23-6
U16, U17, U18, U23: SN74AHC1G04; SOT-553
U19: SN74AHC1G32; SOT-553
U20, U21, U22: SN74AHC1G02; SOT-553

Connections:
+5V: C46.1, C47.1, C48.1, C49.1, C62.1, C63.1, C64.1, C65.1, C66.1, C67.1, C68.1, C69.1, R71.1, U12.5 (~SD), U12.6 (V+), U13.5 (~SD), U13.6 (V+), U14.5 (~SD), U14.6 (V+), U15.5 (~SD), U15.6 (V+), U16.5 (VCC), U17.5 (VCC), U18.5 (VCC), U19.5 (VCC), U20.5 (VCC), U21.5 (VCC), U22.5 (VCC), U23.5 (VCC); also elsewhere on the board
/Automatic Range Switching/Amplified_VDUT: R59.1; also elsewhere on the board
/Automatic Range Switching/Range_Switch_1_ON: U19.4 (Y); also elsewhere on the board
/Automatic Range Switching/Range_Switch_2_ON: U20.4 (Y); also elsewhere on the board
/Automatic Range Switching/Range_Switch_3_ON: U21.4 (Y); also elsewhere on the board
/Automatic Range Switching/Range_Switch_4_ON: U22.4 (Y); also elsewhere on the board
/Automatic Range Switching/Range_Switch_5_ON: U23.4 (Y); also elsewhere on the board
GND: C45.2, C46.2, C47.2, C48.2, C49.2, C50.2, C51.2, C52.2, C53.2, C54.2, C55.2, C56.2, C57.2, C58.2, C59.2, C60.2, C61.2, C62.2, C63.2, C64.2, C65.2, C66.2, C67.2, C68.2, C69.2, D8.2 (A), R61.2, U12.2 (V-), U13.2 (V-), U14.2 (V-), U15.2 (V-), U16.3 (GND), U17.3 (GND), U18.3 (GND), U19.2 (B), U19.3 (GND), U20.3 (GND), U21.3 (GND), U22.3 (GND), U23.3 (GND); also elsewhere on the board
unnamed: C45.1, D8.1 (K), R59.2, U12.3 (-), U13.3 (-), U14.3 (-), U15.3 (-)
unnamed: C50.1, R60.1, R61.1, R62.2, U12.1 (+)
unnamed: C51.1, R63.1, R64.1, R65.2, U13.1 (+)
unnamed: C52.1, R66.1, R67.1, R68.2, U14.1 (+)
unnamed: C53.1, R69.1, R70.1, R71.2, U15.1 (+)
unnamed: C54.1, D9.1 (K), R72.2, U19.1 (A)
unnamed: C55.1, D10.2 (A), R73.2, U20.1 (A)
unnamed: C56.1, D11.1 (K), R74.2, U16.2 (A)
unnamed: C57.1, D12.2 (A), R75.2, U21.1 (A)
unnamed: C58.1, D13.1 (K), R76.2, U17.2 (A)
unnamed: C59.1, D14.2 (A), R77.2, U22.1 (A)
unnamed: C60.1, D15.1 (K), R78.2, U18.2 (A)
unnamed: C61.1, D16.2 (A), R79.2, U23.2 (A)
unnamed: D9.2 (A), D10.1 (K), R60.2, R64.2, R72.1, R73.1, U12.4
unnamed: D11.2 (A), D12.1 (K), R62.1, R63.2, R67.2, R74.1, R75.1, U13.4
unnamed: D13.2 (A), D14.1 (K), R65.1, R66.2, R70.2, R76.1, R77.1, U14.4
unnamed: D15.2 (A), D16.1 (K), R68.1, R69.2, R78.1, R79.1, U15.4
unnamed: U16.4 (Y), U20.2 (B)
unnamed: U17.4 (Y), U21.2 (B)
unnamed: U18.4 (Y), U22.2 (B)

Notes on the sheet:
10mV
300µA-3mA
100mV
Beim Umschalten des Messbereichs muss zuerst der zugehörige Range-MOSFET geschlossen werden bevor der vorherige geöffnet wird, um zu verhindern das der OPA189 im Sättigungsbereich arbeitet.
Pegelwandler
3µA-300µA
300mA-3A
RC Zeitkonstante 100ns
3mA-300mA
MOSFET ON-OFF Verzögerung
Strommessung
Output
VTL
VTH
Range
<3µA

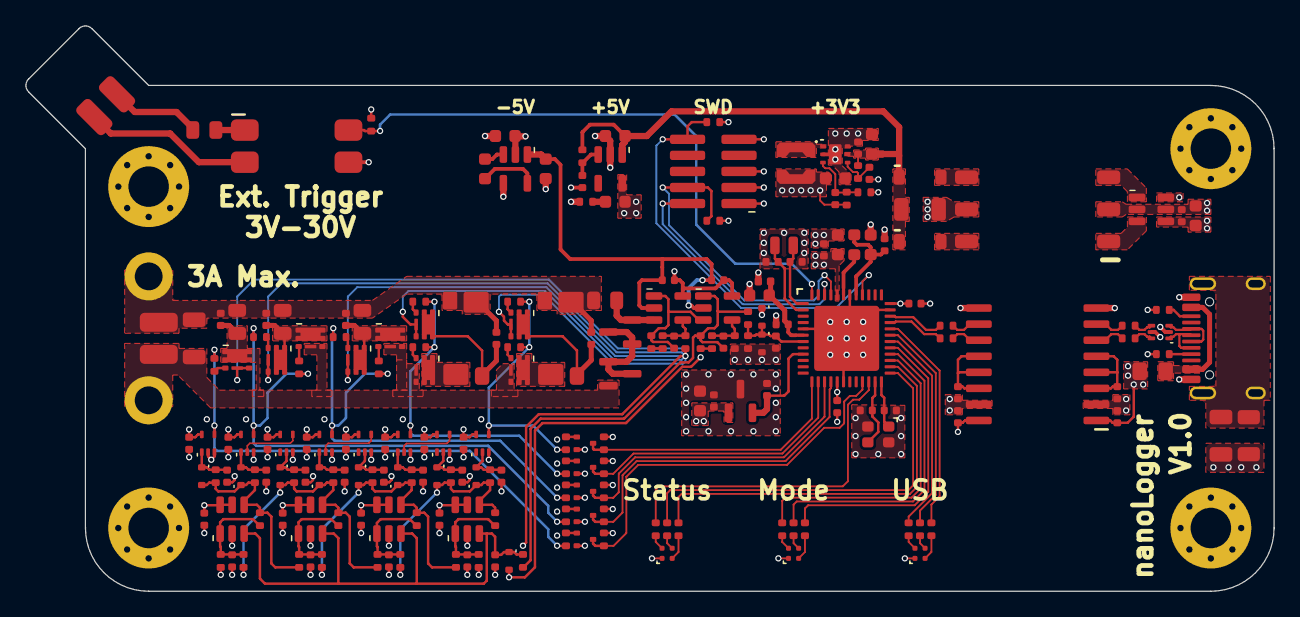
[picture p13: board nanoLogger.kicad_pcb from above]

Board: 4 copper layers, 98.7 x 44.7 mm, 221 parts (0 on the bottom side), 128 nets.

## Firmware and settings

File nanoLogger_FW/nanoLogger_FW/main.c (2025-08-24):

#include <atmel_start.h>
#include <stdio.h>
#include "current_measurement.h"
#include "user_cli.h"
#include "StatusLeds.h"
#include "smarteeprom_user_parameters.h"

int main(void)
{
	/* Initializes MCU, drivers and middleware */
	atmel_start_init();
	
	adc_sync_enable_channel(&ADC_0, 0);
	
	usb_cli_init();
	
	//** Default Device Config **//
	nanoLogger_t nanoLogger;
	nanoLogger.deviceConfig.deviceMode = DEVICE_IDLE;
	nanoLogger.deviceConfig.triggerConfig = NO_EXT_TRIGGER;
	nanoLogger.deviceConfig.sampleRate = 0;
	nanoLogger.deviceConfig.recordLength = 0;
	nanoLogger.deviceConfig.samples = 1;
	nanoLogger.currentMeasurement.adcResolution = ADC_16BIT;
	
	//** Load Calibration Parameters from SmartEEPROM or Write Default Values **//
	if(smarteeprom_load_user_parameters(&nanoLogger) == SMARTEEPROM_SIGNATURE_INVALID) smarteeprom_write_user_parameters_default(&nanoLogger);
	
	//** Set Default ADC Resolution & Gain correction **//
	set_adc_resolution(&nanoLogger.currentMeasurement);
	set_adc_gaincorrection(&nanoLogger.currentMeasurement);
	
	//** Init LED Task **//
	timer0_led_task_init();

	while (1) {
		
		usb_cli_process_received_data(&nanoLogger);
		usb_cli_execute_operation(&nanoLogger);
		
	}
}

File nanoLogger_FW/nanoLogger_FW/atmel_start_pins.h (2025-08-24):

/*
 * Code generated from Atmel Start.
 *
 * This file will be overwritten when reconfiguring your Atmel Start project.
 * Please copy examples or other code you want to keep to a separate file
 * to avoid losing it when reconfiguring.
 */
#ifndef ATMEL_START_PINS_H_INCLUDED
#define ATMEL_START_PINS_H_INCLUDED

#include <hal_gpio.h>

// SAMD51 has 14 pin functions

#define GPIO_PIN_FUNCTION_A 0
#define GPIO_PIN_FUNCTION_B 1
#define GPIO_PIN_FUNCTION_C 2
#define GPIO_PIN_FUNCTION_D 3
#define GPIO_PIN_FUNCTION_E 4
#define GPIO_PIN_FUNCTION_F 5
#define GPIO_PIN_FUNCTION_G 6
#define GPIO_PIN_FUNCTION_H 7
#define GPIO_PIN_FUNCTION_I 8
#define GPIO_PIN_FUNCTION_J 9
#define GPIO_PIN_FUNCTION_K 10
#define GPIO_PIN_FUNCTION_L 11
#define GPIO_PIN_FUNCTION_M 12
#define GPIO_PIN_FUNCTION_N 13

#define RANGE_SWITCH_POSITION_5 GPIO(GPIO_PORTA, 8)
#define RANGE_SWITCH_POSITION_4 GPIO(GPIO_PORTA, 9)
#define RANGE_SWITCH_POSITION_3 GPIO(GPIO_PORTA, 10)
#define RANGE_SWITCH_POSITION_2 GPIO(GPIO_PORTA, 11)
#define RANGE_SWITCH_POSITION_1 GPIO(GPIO_PORTA, 12)
#define STATUS_LED_RED GPIO(GPIO_PORTA, 13)
#define STATUS_LED_GREEN GPIO(GPIO_PORTA, 16)
#define STATUS_LED_BLUE GPIO(GPIO_PORTA, 17)
#define MODE_LED_RED GPIO(GPIO_PORTA, 18)
#define MODE_LED_GREEN GPIO(GPIO_PORTA, 19)
#define MODE_LED_BLUE GPIO(GPIO_PORTA, 20)
#define USB_STATUS_LED_RED GPIO(GPIO_PORTA, 21)
#define USB_STATUS_LED_GREEN GPIO(GPIO_PORTA, 22)
#define USB_STATUS_LED_BLUE GPIO(GPIO_PORTA, 23)
#define USB_M GPIO(GPIO_PORTA, 24)
#define USB_P GPIO(GPIO_PORTA, 25)
#define EXTERNAL_TRIGGER GPIO(GPIO_PORTB, 3)
#define CURRENT_MONITOR GPIO(GPIO_PORTB, 8)

#endif // ATMEL_START_PINS_H_INCLUDED

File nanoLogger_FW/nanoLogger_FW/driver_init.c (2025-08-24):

/*
 * Code generated from Atmel Start.
 *
 * This file will be overwritten when reconfiguring your Atmel Start project.
 * Please copy examples or other code you want to keep to a separate file
 * to avoid losing it when reconfiguring.
 */

#include "driver_init.h"
#include <peripheral_clk_config.h>
#include <utils.h>
#include <hal_init.h>

#include <hpl_adc_base.h>
#include <hpl_rtc_base.h>

struct timer_descriptor TIMER_RTC;
struct timer_descriptor TIMER_TC;
struct timer_descriptor TIMER_LOGGING;

struct adc_sync_descriptor ADC_0;

void ADC_0_PORT_init(void)
{

	// Disable digital pin circuitry
	gpio_set_pin_direction(CURRENT_MONITOR, GPIO_DIRECTION_OFF);

	gpio_set_pin_function(CURRENT_MONITOR, PINMUX_PB08B_ADC0_AIN2);
}

void ADC_0_CLOCK_init(void)
{
	hri_mclk_set_APBDMASK_ADC0_bit(MCLK);
	hri_gclk_write_PCHCTRL_reg(GCLK, ADC0_GCLK_ID, CONF_GCLK_ADC0_SRC | (1 << GCLK_PCHCTRL_CHEN_Pos));
}

void ADC_0_init(void)
{
	ADC_0_CLOCK_init();
	ADC_0_PORT_init();
	adc_sync_init(&ADC_0, ADC0, (void *)NULL);
}

void EXTERNAL_IRQ_0_init(void)
{
	hri_gclk_write_PCHCTRL_reg(GCLK, EIC_GCLK_ID, CONF_GCLK_EIC_SRC | (1 << GCLK_PCHCTRL_CHEN_Pos));
	hri_mclk_set_APBAMASK_EIC_bit(MCLK);

	// Set pin direction to input
	gpio_set_pin_direction(EXTERNAL_TRIGGER, GPIO_DIRECTION_IN);

	gpio_set_pin_pull_mode(EXTERNAL_TRIGGER,
	                       // <y> Pull configuration
	                       // <id> pad_pull_config
	                       // <GPIO_PULL_OFF"> Off
	                       // <GPIO_PULL_UP"> Pull-up
	                       // <GPIO_PULL_DOWN"> Pull-down
	                       GPIO_PULL_OFF);

	gpio_set_pin_function(EXTERNAL_TRIGGER, PINMUX_PB03A_EIC_EXTINT3);

	ext_irq_init();
}

/**
 * \brief Timer initialization function
 *
 * Enables Timer peripheral, clocks and initializes Timer driver
 */
static void TIMER_RTC_init(void)
{
	hri_mclk_set_APBAMASK_RTC_bit(MCLK);
	timer_init(&TIMER_RTC, RTC, _rtc_get_timer());
}

void delay_driver_init(void)
{
	delay_init(SysTick);
}

/**
 * \brief Timer initialization function
 *
 * Enables Timer peripheral, clocks and initializes Timer driver
 */
static void TIMER_TC_init(void)
{
	hri_mclk_set_APBAMASK_TC0_bit(MCLK);
	hri_gclk_write_PCHCTRL_reg(GCLK, TC0_GCLK_ID, CONF_GCLK_TC0_SRC | (1 << GCLK_PCHCTRL_CHEN_Pos));

	timer_init(&TIMER_TC, TC0, _tc_get_timer());
}

/**
 * \brief Timer initialization function
 *
 * Enables Timer peripheral, clocks and initializes Timer driver
 */
static void TIMER_LOGGING_init(void)
{
	hri_mclk_set_APBBMASK_TC2_bit(MCLK);
	hri_gclk_write_PCHCTRL_reg(GCLK, TC2_GCLK_ID, CONF_GCLK_TC2_SRC | (1 << GCLK_PCHCTRL_CHEN_Pos));

	timer_init(&TIMER_LOGGING, TC2, _tc_get_timer());
}

void USB_DEVICE_INSTANCE_PORT_init(void)
{

	gpio_set_pin_direction(USB_M,
	                       // <y> Pin direction
	                       // <id> pad_direction
	                       // <GPIO_DIRECTION_OFF"> Off
	                       // <GPIO_DIRECTION_IN"> In
	                       // <GPIO_DIRECTION_OUT"> Out
	                       GPIO_DIRECTION_OUT);

	gpio_set_pin_level(USB_M,
	                   // <y> Initial level
	                   // <id> pad_initial_level
	                   // <false"> Low
	                   // <true"> High
	                   false);

	gpio_set_pin_pull_mode(USB_M,
	                       // <y> Pull configuration
	                       // <id> pad_pull_config
	                       // <GPIO_PULL_OFF"> Off
	                       // <GPIO_PULL_UP"> Pull-up
	                       // <GPIO_PULL_DOWN"> Pull-down
	                       GPIO_PULL_OFF);

	gpio_set_pin_function(USB_M,
	                      // <y> Pin function
	                      // <id> pad_function
	                      // <i> Auto : use driver pinmux if signal is imported by driver, else turn off function
	                      // <PINMUX_PA24H_USB_DM"> Auto
	                      // <GPIO_PIN_FUNCTION_OFF"> Off
	                      // <GPIO_PIN_FUNCTION_A"> A
	                      // <GPIO_PIN_FUNCTION_B"> B
	                      // <GPIO_PIN_FUNCTION_C"> C
	                      // <GPIO_PIN_FUNCTION_D"> D
	                      // <GPIO_PIN_FUNCTION_E"> E
	                      // <GPIO_PIN_FUNCTION_F"> F
	                      // <GPIO_PIN_FUNCTION_G"> G
	                      // <GPIO_PIN_FUNCTION_H"> H
	                      // <GPIO_PIN_FUNCTION_I"> I
	                      // <GPIO_PIN_FUNCTION_J"> J
	                      // <GPIO_PIN_FUNCTION_K"> K
	                      // <GPIO_PIN_FUNCTION_L"> L
	                      // <GPIO_PIN_FUNCTION_M"> M
	                      // <GPIO_PIN_FUNCTION_N"> N
	                      PINMUX_PA24H_USB_DM);

	gpio_set_pin_direction(USB_P,
	                       // <y> Pin direction
	                       // <id> pad_direction
	                       // <GPIO_DIRECTION_OFF"> Off
	                       // <GPIO_DIRECTION_IN"> In
	                       // <GPIO_DIRECTION_OUT"> Out
	                       GPIO_DIRECTION_OUT);

	gpio_set_pin_level(USB_P,
	                   // <y> Initial level
	                   // <id> pad_initial_level
	                   // <false"> Low
	                   // <true"> High
	                   false);

	gpio_set_pin_pull_mode(USB_P,
	                       // <y> Pull configuration
	                       // <id> pad_pull_config
	                       // <GPIO_PULL_OFF"> Off
	                       // <GPIO_PULL_UP"> Pull-up
	                       // <GPIO_PULL_DOWN"> Pull-down
	                       GPIO_PULL_OFF);

	gpio_set_pin_function(USB_P,
	                      // <y> Pin function
	                      // <id> pad_function
	                      // <i> Auto : use driver pinmux if signal is imported by driver, else turn off function
	                      // <PINMUX_PA25H_USB_DP"> Auto
	                      // <GPIO_PIN_FUNCTION_OFF"> Off
	                      // <GPIO_PIN_FUNCTION_A"> A
	                      // <GPIO_PIN_FUNCTION_B"> B
	                      // <GPIO_PIN_FUNCTION_C"> C
	                      // <GPIO_PIN_FUNCTION_D"> D
	                      // <GPIO_PIN_FUNCTION_E"> E
	                      // <GPIO_PIN_FUNCTION_F"> F
	                      // <GPIO_PIN_FUNCTION_G"> G
	                      // <GPIO_PIN_FUNCTION_H"> H
	                      // <GPIO_PIN_FUNCTION_I"> I
	                      // <GPIO_PIN_FUNCTION_J"> J
	                      // <GPIO_PIN_FUNCTION_K"> K
	                      // <GPIO_PIN_FUNCTION_L"> L
	                      // <GPIO_PIN_FUNCTION_M"> M
	                      // <GPIO_PIN_FUNCTION_N"> N
	                      PINMUX_PA25H_USB_DP);
}

/* The USB module requires a GCLK_USB of 48 MHz ~ 0.25% clock
 * for low speed and full speed operation. */
#if (CONF_GCLK_USB_FREQUENCY > (48000000 + 48000000 / 400)) || (CONF_GCLK_USB_FREQUENCY < (48000000 - 48000000 / 400))
#warning USB clock should be 48MHz ~ 0.25% clock, check your configuration!
#endif
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
